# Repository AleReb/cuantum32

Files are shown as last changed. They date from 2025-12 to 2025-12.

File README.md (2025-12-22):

# Sistema de Análisis de Opiniones Distribuido I2C

## Changelog / Recent Updates (Quantum32 V3)
- **2025-12-22**:
  - **Fixed Blocking**: Master V3 now updates the OLED display continuously, even during high-speed Python batched sampling.
  - **Fixed Slave LED**: Slaves now explicitly use **Pin 7** for the status LED and give visual feedback on every I2C RX/TX event.
  - **Environment**: Fixed local Python environment initialization.

Sistema distribuido basado en Arduino que utiliza comunicación I2C para coordinar múltiples dispositivos esclavos que realizan análisis de opiniones (a favor/en contra/neutral). El maestro agrega los resultados y los muestra en una pantalla OLED con marcas de tiempo del RTC.

## 📋 Descripción

Este proyecto implementa una **simulación pedagógica de holografía (Toy Holography)** inspirada en el principio holográfico y la correspondencia AdS/CFT. Utiliza una arquitectura maestro-esclavo donde:

- **Maestro (Bulk)**: Representa el volumen ("bulk") del espacio-tiempo. Reconstruye información lógica a partir de las correlaciones de los esclavos, monitorea el ambiente y visualiza la "reconstrucción holográfica".
- **Esclavos (Boundary)**: Representan el borde ("boundary") del sistema. Generan observables locales con ruido y pérdida simulada que el maestro utiliza para inferir el estado del volumen.

El sistema ilustra cómo propiedades, corrección de errores y geometrías emergentes pueden surgir de interacciones distribuidas simples sobre un bus I2C.

## 🔧 Hardware Requerido

### Maestro (Master)
- 1x ESP32-S3 Super Mini (o compatible)
- 1x Pantalla OLED 1.3" (SH1106, dirección I2C 0x3C)
- 1x Módulo RTC DS3231 (dirección I2C 0x68)
- 1x Sensor BME280 (Temp/Hum/Pres, dirección I2C 0x76)
- 1x Módulo MicroSD (SPI: CS=7, MOSI=6, MISO=5, SCLK=4)
- 1x LED RGB (NeoPixel/WS2812B en pin 48)
- Resistencias pull-up 4.7kΩ (2x para SDA y SCL)

### Cada Esclavo (Slave)
- 1x Arduino (Uno, Nano, ESP32, etc.)
- Conexión al bus I2C compartido

### Adicional
- Cables jumper
- Fuente de alimentación adecuada (si se usan múltiples dispositivos)
- Protoboard o PCB para conexiones

### 2. Configurar el Maestro
1. Abrir `master.ino` en Arduino IDE
2. Revisar `config.h` para ajustar configuraciones si es necesario (pines, direcciones, habilitar/deshabilitar módulos)
3. Conectar el Arduino maestro
4. Seleccionar placa y puerto correcto
5. Cargar el código

### 3. Configurar los Esclavos
Para **cada esclavo**:
1. Abrir `slave.ino` en Arduino IDE
2. **IMPORTANTE**: Cambiar la dirección I2C única:
   ```cpp
   #define SLAVE_ADDRESS 0x10  // Cambiar a 0x11, 0x12, 0x13, etc.
   ```
3. Conectar el Arduino esclavo
4. Cargar el código
5. Repetir para cada esclavo adicional

### 4. Conexiones de Hardware
Ver [WIRING.md](WIRING.md) para diagramas detallados de conexión.

**Conexiones básicas I2C:**
- Conectar **SDA** de todos los dispositivos juntos
- Conectar **SCL** de todos los dispositivos juntos
- Conectar **GND** común
- Agregar resistencias pull-up de 4.7kΩ en SDA y SCL al voltaje de alimentación (3.3V o 5V según dispositivos)

## ⚙️ Configuración Avanzada

### Agregar Más Esclavos
1. Editar `config.h` en el maestro:
   ```cpp
   const uint8_t SLAVE_ADDRESSES[] = {
     SLAVE_ADDR_1,
     SLAVE_ADDR_2,
     SLAVE_ADDR_3,
     SLAVE_ADDR_4,
     0x14,  // Nuevo esclavo 5
     0x15   // Nuevo esclavo 6
   };
   ```
2. Programar nuevos esclavos con direcciones únicas
3. Conectar al bus I2C

### Habilitar/Deshabilitar Módulos
En `config.h` puedes activar o desactivar componentes:
```cpp
#define ENABLE_OLED       true   // Pantalla OLED
#define ENABLE_RTC        true   // Reloj RTC
#define ENABLE_SD_LOGGING true   // Registro en SD
#define ENABLE_BME280     true   // Sensor ambiental
#define ENABLE_RGB_LED    true   // LED de estado
```

### Ajustar Velocidad I2C
En `config.h`:
```cpp
#define I2C_CLOCK_SPEED 100000  // 100 kHz (estándar) o 400000 (rápido)
```

## 📊 Uso

### Monitor Serial
Abrir el monitor serial (115200 baud) para ver:
- Escaneo de dispositivos I2C al inicio
- Resultados agregados en tiempo real
- Confirmación de escritura en SD (`>> Data saved to SD`)
- Mensajes de error o advertencias

### Pantalla OLED (MasterV2)
La pantalla ahora visualiza la dinámica de la simulación en tiempo real:
- **Header**: `T:####` (Contador de Ticks de simulación).
- **Status Row**: Estado de cada esclavo (Cuadro lleno = OK, Vacío = Missing).
- **Bulk Reconstruction**: Barra de progreso que muestra qué porcentaje de la lógica del "bulk" ha sido recuperada exitosamente desde el borde.
  - El porcentaje se muestra centrado con contraste dinámico para evitar solapamiento.
- **Boundary Map (2x2)**: Visualización matricial del ruido en cada esclavo (cuadros más llenos = menos ruido/mejor señal).
- **History Graph**: Un gráfico histórico a la derecha que muestra la evolución de la `Reconstruction Ratio` en los últimos 40 ticks.
- **Footer**: Máscaras de bits (Boundary/Bulk) y datos ambientales.

### Registro en Tarjeta SD
El sistema registra en `datalog.csv`:
`timestamp, tick, active_slaves, boundary_mask, bulk_mask, recon_ratio, loss_sum, noise_avg, temp, hum`

### Disclaimer de "Veracidad Científica"
> [!IMPORTANT]
> **Nota sobre la precisión científica**:
> Este código es un **"modelo de juguete" (toy model)** con fines educativos y de prototipado.
> *   **No es** una simulación cuántica real (no hay entrelazamiento cuántico real ni hamiltonianos complejos).
> *   La "Reconstrucción del Bulk" usa una lógica de máscaras de bits simplificada para *ilustrar* conceptos de corrección de errores cuánticos, pero no implementa un código corrección de errores (QECC) riguroso como el código de HaPPY o Shor.
> *   Su objetivo es proveer una intuición física de cómo información local en el borde puede redundar en información robusta en el volumen, usando hardware clásico accesible.

## 🔍 Solución de Problemas

### No se detectan dispositivos I2C
- Verificar conexiones SDA/SCL
- Confirmar resistencias pull-up instaladas (4.7kΩ)
- Revisar alimentación de todos los dispositivos
- Usar sketch de escaneo I2C para detectar dispositivos

### OLED no muestra nada
- Verificar dirección I2C (0x3C o 0x3D)
- Confirmar librería correcta (SH1106 vs SSD1306)
- Revisar conexiones y alimentación

### Esclavos no responden
- Verificar direcciones únicas para cada esclavo
- Confirmar que los esclavos están alimentados
- Revisar que el código del esclavo se cargó correctamente
- Verificar timeout en `config.h` (aumentar si es necesario)

### Error en SD Card
- Verificar conexiones SPI (CS, MOSI, MISO, SCLK)
- Asegurar que la tarjeta está formateada en FAT32
- Revisar si el archivo `datalog.csv` está abierto en otro lugar

## 🛠️ Desarrollo Futuro

Posibles mejoras:
- [ ] Implementar checksums para validación de datos
- [ ] Agregar comandos de configuración desde el maestro
- [ ] Interfaz web para visualización remota
- [ ] Modo de bajo consumo para operación con batería
- [*] Implementar cuantum life! revisa la carpeta cuantum_life para ver el código del juego de la vida. 

## 👤 Autor

**Alejandro Rebolledo**  
Email: arebolledo@udd.cl  
Fecha: 2025-12-01  

**Atribución Original**
El código original fue creado por **Vicente Lorca** [@vlorcap](https://github.com/vlorcap) ; este proyecto es un derivado y el concepto inicial proviene de Vicente.

## 📄 Licencia

Este proyecto está licenciado bajo **Creative Commons Attribution-NonCommercial 4.0 International (CC BY-NC 4.0)**.

Ver el archivo [LICENSE](LICENSE) para más detalles.

### Descargo de Responsabilidad

Este código se proporciona "tal cual", sin garantías de ningún tipo, expresas o implícitas. El autor no se hace responsable de ningún daño o pérdida que pueda resultar del uso de este código. Úselo bajo su propio riesgo.

## 🤝 Contribuciones

Las contribuciones son bienvenidas. Por favor:
1. Fork el proyecto
2. Crea una rama para tu feature (`git checkout -b feature/AmazingFeature`)
3. Commit tus cambios (`git commit -m 'Add some AmazingFeature'`)
4. Push a la rama (`git push origin feature/AmazingFeature`)
5. Abre un Pull Request

## 📞 Soporte

Para preguntas o problemas, por favor abre un issue en el repositorio de GitHub.

---

**¡Gracias por usar este proyecto!** ⭐ Si te resulta útil, considera darle una estrella al repositorio.

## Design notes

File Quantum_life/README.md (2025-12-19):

# Cuantum Life: Holographic Edition (v1.2)

**Cuantum Life** is a specialized implementation of Conway's Game of Life for the **Cuantum32** hardware, merging "Fast Life" optimization with the "MasterV2" holographic architecture.

## The Concept

This project implements a **Holographic Universe** metaphor:

*   **The Bulk (OLED Screen)**: Represents the emergent spacetime where the "Life" simulation occurs.
*   **The Boundary (I2C Slaves)**: Represents the "holographic screen" or "event horizon" surrounding the universe.

In standard Game of Life, the universe is closed and often dies (heat death) or freezes (stable loops). In **Cuantum Life**, the universe is **open**. The I2C Slaves act as entropy sources, injecting fluctuations (random cells) into the Bulk:
1.  **Reactive**: If a slave detects high noise (from real-world sensors), it immediately injects life.
2.  **Spontaneous**: Even in silence, each slave acts as a quantum fluctuation source, injecting life automatically every 2-8 seconds.

See [game_of_life_concept.md](game_of_life_concept.md) for a full theoretical explanation.

## Controls

*   **Button A (GPIO 2)**: **Reset / Big Bang**. Restarts the unknown universe with a new random seed.
*   **Button B (GPIO 1)**: **Scale Toggle**. Switches between:
    *   *Scale 1*: 128x64 resolution (1 pixel per cell). High detail, slower.
    *   *Scale 2*: 64x32 resolution (2x2 pixels per cell). Chunky, retro, easier to see.

## Feedback Systems

### 1. Visual Feedback (OLED)
*   **Active Slaves**: Small circular indicators appear in the 4 corners of the screen if the corresponding Slave (0-3) is connected and active.
*   **Interaction Flash**: When a Slave injects "life" (entropy) into the system, its sector of the screen momentarily flashes inverted colors.

### 2. Status LED (NeoPixel)
The RGB LED acts as a "Universe Health Monitor", changing color based on **Population Density**:
*   **Blue/Cyan**: Low density (Sparse, expanding universe).
*   **Purple**: Medium density (Stable growth).
*   **Red**: High density (Crowded).
*   **White (Bright)**: Overpopulation or "Injection Flash" (Energy burst from boundary).

### 3. Serial Monitor (Debug)
Connect at **115200 baud** to see real-time statistics (1Hz):
*   `Gen`: Current generation number.
*   `Pop`: Total population count.
*   `Slaves`: Connectivity status and Noise levels for each node (e.g., `[0:OK N=0.45]`).

## Hardware Configuration (Cuantum32)

*   **Master**: ESP32
*   **Display**: SH1106 OLED (0x3C)
*   **Storage**: SD Card (HSPI: CS=7, MOSI=6, MISO=4, CLK=5)
*   **Feedback**: NeoPixel (Pin 48)
*   **I2C Slaves**: Addresses 0x10, 0x11, 0x12, 0x13.

## License

Creative Commons Attribution-NonCommercial 4.0 International (CC BY-NC 4.0).
**Author**: Alejandro Rebolledo (arebolledo@udd.cl)

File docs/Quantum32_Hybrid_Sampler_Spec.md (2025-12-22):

# Quantum32 Hybrid Sampler Spec
**Filename:** `docs/Quantum32_Hybrid_Sampler_Spec.md`  
**Project name:** **Quantum32 Hybrid Sampler (QHS)**  
**Status:** Implementable specification (Master/Slave **V3** derived from **V2**)  
**Primary goal:** Turn Quantum32 from a purely pedagogical “toy holography” demo into a **hardware-in-the-loop stochastic sampler** that a **PC/notebook** can use for **combinatorial optimization** (e.g., Max-Cut) and as a stepping stone toward **RBM negative-phase sampling**.

---

## 1. Scope and non-goals

### 1.1 In-scope
- Keep the existing **Master–Slave I2C** architecture.
- Use **V2 code style** (non-blocking, no fatal aborts) as the baseline.
- Implement **bidirectional** control:
  - **PC → Master → Slaves:** parameters and run control.
  - **Slaves → Master → PC:** **observables only** (no full state streaming for PoC).
- Provide a clean data contract so a **second AI** can work on the repo without guessing.

### 1.2 Explicit non-goals (for the PoC)
- No “all-training-on-ESP32”.
- No large state vectors over I2C.
- No guarantee of equilibrium or detailed-balance sampling.
- No claims of “quantum”; this is **stochastic classical sampling**.

---

## 2. Engineering constraints (must-haves)

These are repo-level rules for **all new code** (Master V3 and Slave V3):

1) **No `while(1){}`** to indicate fatal errors.  
2) **No `return;` inside `setup()`** to abort boot.  
3) Always continue initialization; use:
   - **global boolean flags** per subsystem  
   - **Serial diagnostics** in `loop()`  
   - periodic **retry** using `millis()` scheduling  
4) No heavy work inside I2C callbacks (`onReceive`, `onRequest`).

---

## 3. Repository baseline

### 3.1 Relevant folders (current repo)
- `masterV2/masterV2.ino` — non-blocking master baseline
- `cuantumsV2/cuantumsV2.ino` — non-blocking slave baseline
- `master/config.h` — useful pin definitions and feature flags (even if V2 currently uses defaults)
- `docs/` — conceptual and visualization documents
- `WIRING.md` — wiring notes

### 3.2 Current V2 data protocol (as implemented)
**Slave receives (from Master)**
- Tick command:  
  `T,<tick>,<mode>,<noise>\n`  
  Parsed in slave V2 via `parseTickCommand(...)`.

**Slave responds (to Master on I2C request)**
- Observable response:  
  `O,<tick>,<bmask>,<loss>,<noise>,<seed>\n`

**Master parses (from Slave)**
- `sscanf(buf, "%c,%lu,%u,%u,%f,%lu", &prefix, &tick, &bmask, &loss, &noise, &seed)`

This spec keeps those **as the compatible baseline**.

---

## 4. Target architecture (Hybrid Sampler)

### 4.1 Roles
**Hardware**
- Runs **p-bit-like dynamics** on each slave.
- Emits **observables** (compact summaries) that represent sampled configurations.
- Applies parameters from PC (via Master).

**PC/Notebook**
- Defines an objective (e.g., Max-Cut on a graph).
- Requests batches, evaluates scores, and updates parameters (annealing schedule or learned control).
- Logs and plots metrics (mixing/diversity) to validate PoC.

### 4.2 Minimal hybrid loop
1) PC connects to Master over USB Serial.
2) PC sets parameters (T, bias, coupling, mode).
3) Master pushes params to all slaves over I2C.
4) PC requests a batch of **K** samples; Master orchestrates ticks and collects observables.
5) PC computes:
   - Max-Cut score (or other objective)
   - diversity and autocorrelation metrics
6) PC updates parameters and repeats.

---

## 5. Data model: Observables

### 5.1 Per-slave observable record
A single record corresponds to “what one slave produced for a given tick”.

| Field | Type | Meaning | Notes |
|---|---:|---|---|
| `tick` | uint32 | global tick id | set by Master |
| `slave_id` | uint8 | index of slave in Master list | added by Master when streaming to PC |
| `bmask` | uint16 | compact boundary configuration | treated as “observable microstate” |
| `loss` | uint16 | proxy loss / mismatch counter | pedagogy or objective proxy |
| `noise` | float (2–3 dp) | effective temperature | should match parameter T |
| `seed` | uint32 | PRNG state / nonce | helps debug non-determinism |

**Why `bmask` counts as “observable”:** it is not the full internal state; it is a compact, lossy view that is enough for PoC optimization and sampler validation.

### 5.2 Batch stream format to PC
To keep parsing robust, Master MUST prefix machine-readable lines with `@` (control) and use `O,` lines strictly for data.

Example:
```
@BATCH RUN=12 T=0.20 B=10 Kp=40 M=1 K=100 STRIDE=1 BURN=20
O,1234,0,9,2,0.20,30123456
O,1234,1,3,0,0.20,99123001
...
@DONE RUN=12 LASTTICK=1333
```

---

## 6. Parameter model (PC → hardware)

### 6.1 Parameters to control (PoC)
| Name | Symbol | Type | Range | Meaning |
|---|---|---|---|---|
| Noise / Temperature | `T` | float | 0.00–1.00 | flip intensity / randomness |
| Bias | `B` | int8 | -127..127 | pushes configurations toward 0/1 patterns |
| Coupling | `Kp` | uint8 | 0..255 | introduces correlation / smoothness |
| Mode | `M` | uint8 | 0..255 | selects dynamics variant |

**Notes**
- V2 already supports `T` and `M` (via the tick command).
- V3 introduces `B` and `Kp` and moves parameters into a dedicated command (recommended).

### 6.2 Annealing schedules (PC side)
Two supported patterns:
1) **Manual schedule:** PC sweeps T from high → low.
2) **Adaptive schedule:** PC updates T/B/Kp based on score improvements.

---

## 7. Communication protocols

### 7.1 I2C: Master ↔ Slaves
**Constraints**
- Typical I2C read buffer is small; V2 uses **≤32 bytes** reads.
- Keep message lengths under 32 bytes for PoC. Avoid chunking in V3 unless needed.

#### 7.1.1 V3 I2C commands
To keep compatibility, do not break V2; add one new command type.

1) **SET_PARAMS** (new in V3)  
   `P,<T>,<B>,<Kp>,<M>\n`  
   - Sent infrequently (only when parameters change).
   - Slaves store parameters; do not compute heavy updates inside callback.

2) **TICK** (existing V2)  
   Keep V2 tick for synchronization:
   - Option A (compatible): `T,<tick>,<M>,<T>\n`
   - Option B (cleaner): `T,<tick>\n` and rely on last `P` for params.

**Recommendation:** Use **Option B** in V3 (short, robust) once `P` exists; keep Option A as fallback during migration.

#### 7.1.2 Slave response (unchanged)
`O,<tick>,<bmask>,<loss>,<noise>,<seed>\n`

### 7.2 Serial: PC ↔ Master
**Transport:** USB Serial @ 115200 (default)

#### 7.2.1 PC → Master commands
- `@HELLO`
- `@SET T=0.20 B=10 Kp=40 M=1`
- `@GET K=200 STRIDE=1 BURN=20`
- `@STOP`

#### 7.2.2 Master → PC responses
- `@HELLO OK FW=MasterV3 SLAVES=4`
- `@ACK ...` / `@ERR ...`
- `@STATUS ...` (periodic health)
- `@BATCH ...`, data lines `O,...`, `@DONE ...`

---

## 8. Non-blocking state machines

### 8.1 Master V3 state machine
- `BOOT`
- `INIT` (set flags; never abort)
- `IDLE` (wait for PC commands)
- `APPLY_PARAMS` (push `P` to all slaves with retry counters)
- `SAMPLING`
  - schedule ticks
  - request slave responses
  - stream `O,...` lines to PC
- `DEGRADED` (optional) if I2C is down; still respond to PC with errors and status

**Non-blocking rule:** each `loop()` iteration must do a small bounded amount of work (e.g., poll one slave per loop).

### 8.2 Slave V3 state machine
- `BOOT`
- `READY`
- `RX_PENDING` (flag set by `onReceive`)
- `DYNAMICS_STEP` (time-sliced updates)
- `BUILD_TX` (prepare `O,...` response in a buffer)
- `REQUEST` (I2C request event reads the prepared buffer only)

---

## 9. Failure policy and observability

### 9.1 Master global flags (minimum)
- `bool i2cOK`
- `bool pcLinkOK` (recent Serial command seen)
- `bool slaveOK[NUM_SLAVES]` (timeout-based, e.g., lastRxMs)
- optional peripheral flags if enabled later: `sdOK`, `oledOK`, `rtcOK`, `bmeOK`, `rgbOK`

### 9.2 Retry policy
- I2C init retry every 2–5 s if bus failed.
- Per-slave command retry counters for `P` and `T` (do not stall the whole system if one slave fails).
- If a slave is missing, keep sampling with remaining slaves.

### 9.3 Logging
- Serial logs for humans:
  - `[INIT] ...`, `[I2C] ...`, `[WARN] ...`
- Serial stream for PC:
  - `@...` control + `O,...` data

SD logging is optional for PoC; if enabled, log **batches** rather than every tick to reduce overhead.

---

## 10. PoC acceptance criteria

The PoC is “approved” if the following can be shown with plots/logs:

### 10.1 Operational robustness
- Runs for **≥30 minutes** without lockups, while:
  - one slave is unplugged/replugged, and/or
  - PC disconnects/reconnects Serial.

### 10.2 Sampler behavior vs temperature
For at least 3 T values (e.g., 0.05, 0.20, 0.50), using K≥200 samples per condition:
- **Diversity increases with T**
  - `unique(bmask)/K` increases as T increases
- **Autocorrelation decreases with T**
  - correlation time (lag where autocorr < 0.2) decreases as T increases

### 10.3 Optimization utility (Max-Cut demo)
Using a small fixed graph (ring or random sparse graph):
- Best Max-Cut score found at low T is **≥** best score at high T baseline.
- A basic annealing schedule T high → low improves best score over fixed T.

---

## 11. Implementation plan (recommended PR sequence)

### PR-1: Serial protocol on Master (no sampling changes)
- Add `@HELLO`, `@SET`, `@GET`, `@STOP`
- Add `@STATUS` periodic line
- Keep V2 I2C tick/response unchanged

### PR-2: Add `P` command (SET_PARAMS) end-to-end
- Master: send `P,<T>,<B>,<Kp>,<M>`
- Slave: parse `P` in loop (non-blocking)
- Keep `T` as synchronization tick only

### PR-3: Sampling driver + batching
- Master: orchestrate burn-in, stride, K batch size
- Stream `@BATCH`, `O,...`, `@DONE`

### PR-4: PC reference client + metrics
- Python:
  - connect, set params, request batches
  - compute diversity + autocorrelation
  - compute Max-Cut objective from bmask mapping
  - export CSV

### PR-5: Documentation + reproducible demo
- Update `docs/` with:
  - wiring assumptions
  - run commands
  - expected output examples
  - plots for PoC criteria

---

## 12. Files to add to the repository

Recommended additions (keep current folders intact):
- `docs/Quantum32_Hybrid_Sampler_Spec.md` (this file)
- `masterV3/` (new)  
  - `masterV3.ino`
- `cuantumsV3/` (new)  
  - `cuantumsV3.ino`
- `pc/` (new)
  - `pc_client_maxcut.py`
  - `metrics.py`
  - `sweep_params.py` (optional)

---

## 13. Reference: mapping bmask to optimization variables

For PoC Max-Cut, treat bits of each slave’s `bmask` as binary variables.

Example:
- `NUM_SLAVES = 4`
- use lower 4 bits of each `bmask` → total **16** variables
- concatenate as: `x = [b0..b3 from slave0, b0..b3 from slave1, ...]`

Max-Cut score:
- For each edge (i, j) with weight w:
  - add w if `x[i] != x[j]`

This is intentionally simple and makes the system immediately useful for “annealing-as-a-service”.

---

## 14. Notes for future extension (RBM / negative phase)

Once the PoC is stable:
- interpret the hardware sampler as a **negative-phase sampler**
- PC computes gradient updates for an RBM using:
  - positive phase from data
  - negative phase from hardware samples (bmask-derived variables)
- Start with tiny RBM (e.g., 8 visible + 8 hidden) and map couplings into local rules gradually.

No RBM claims are part of the PoC; this is a roadmap.

---

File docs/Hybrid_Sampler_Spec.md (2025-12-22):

# Hybrid Sampler Spec (Quantum32)

**Repository:** Quantum32 (ESP32-S3 master + multiple I2C slaves)  
**Goal:** Extend the existing I2C master/slave architecture to support a *hybrid training loop* where:
- **Hardware (ESP32 + I2C slaves)** acts as a **non-deterministic sampler** (state generator).
- **PC/Notebook** performs **parameter updates / gradient computation** and requests new samples from hardware.

This document is designed to be explicit enough for another AI (or developer) to implement work in this repo without needing extra context.

---

## 1. Current repository layout (as shipped in the ZIP)

Root (high-level):
- `master/`  
  - `master.ino` (I2C Master v1: aggregates slave results)  
  - `config.h` (feature flags, addresses, pins)
- `masterV2/`  
  - `masterV2.ino` (Master v2 variant)
- `cuantums/`  
  - `cuantums.ino` (Slave v1: returns opinion counts)
- `cuantumsV2/`  
  - `cuantumsV2.ino` (Slave v2: “Non-Blocking” boundary node)
- `docs/`  
  - `quantum_spacetime_sim.md` (conceptual simulation doc)  
  - `visualization_guide.md` (visual interpretation guide)  
  - PDFs (background material)
- `WIRING.md`, `I2C_FIXES.md`, `OLED_MIGRATION.md`, `RGB_LED_GUIDE.md`, `concept.md`, `README.md`
- CAD + Eagle files: `modelo_3d_cuantum32/`, `Cuantum32/`, etc.

**Important:** The existing system already implements:
- Master polling slaves via I2C
- Slaves responding with a compact payload (v1 uses a CSV-like string)
- Optional peripherals controlled by flags (OLED, RTC, SD, BME280, RGB LED)

This spec **extends**; it does not rewrite the architecture.

---

## 2. Terminology

- **Master:** ESP32-S3 device coordinating the network; connected to PC via USB Serial.
- **Slave / Boundary Node:** I2C node returning a payload on request.
- **Sample:** A discrete system state returned to the PC, suitable for “negative phase” sampling (or at minimum, a structured observable derived from that state).
- **Parameters:** Control variables sent from PC → Master → Slaves (e.g., temperature/noise, bias, coupling scalar, or other model parameters).
- **PoC:** Proof-of-concept milestone, minimal but defendable.

---

## 3. Non-negotiable engineering constraints (repo style)

These constraints must be preserved across all new code:

1) **No `while(1){}` infinite blocks** for “fatal error” handling.  
2) **No `return;` from `setup()`** to abort initialization.  
3) Always continue with remaining initializations, using:
- **global boolean flags** for each subsystem  
- **Serial diagnostic messages** in `loop()`  
- optional **retries** (non-blocking; time-based backoff)

This applies to **Master and Slaves**.

---

## 4. What must be defined before writing code

### 4.1. Select baseline firmware versions
Decide which files are the active baseline:
- Master: `master/master.ino` + `master/config.h` **or** `masterV2/masterV2.ino`
- Slave: `cuantumsV2/cuantumsV2.ino` (preferred due to “non-blocking” approach) or `cuantums/cuantums.ino`

**Default recommendation for PoC:** Master v1 + Slave v2 (least disruption; preserves config flags).

### 4.2. Define “sample” for PoC (minimal viable)
Choose one of these formats:

**Option A — Observables only (fastest):**
- Keep current (favor/contra/neutral) and add at least 1–2 extra observables (e.g., local “energy” proxy, magnetization-like scalar).
- Pros: minimal refactor.
- Cons: not a full state sampler.

**Option B — Full discrete state (recommended):**
- Each slave returns a bitset/spin vector chunk (e.g., 8–32 bits).
- Master concatenates into N-bit state and forwards to PC.
- Pros: true sampler; enables mixing/diversity metrics properly.
- Cons: requires defining a compact binary payload.

**PoC target:** Option B with N = 32 or 64 bits.

### 4.3. Define parameter set (PC → hardware)
Minimal parameter set (PoC):
- `T` (temperature/noise strength) : uint8 or fixed-point
- `B` (global bias) : int8
- `K` (global coupling scalar) : uint8 or fixed-point

Optional later:
- per-node bias vector
- per-edge coupling list or sparse adjacency

### 4.4. Define update cadence
- `burn_in_steps` (discarded steps after parameter change)
- `stride` (steps between returned samples)
- `K_samples` (batch size returned per request)

---

## 5. System overview (hybrid loop)

### 5.1. Responsibilities

**Hardware (Master + Slaves)**
- Maintain discrete system dynamics.
- Accept parameters and apply them.
- Generate samples (states/observables) upon request.
- Provide status/health information.

**PC/Notebook**
- Request samples, collect batches.
- Compute metrics:
  - autocorrelation / correlation time (mixing)
  - diversity (unique states, Hamming distance)
  - entropy proxy
- Optionally compute parameter updates (training loop).

### 5.2. High-level sequence

1) PC connects via Serial to Master.
2) PC sends `SET_PARAMS`.
3) Master distributes params to all Slaves via I2C.
4) PC sends `REQUEST_SAMPLES(K)`.
5) Master triggers sampling and returns K samples (or aggregated batch).
6) PC computes metrics and decides next params; loop repeats.

---

## 6. Communication specifications

### 6.1. PC ↔ Master transport
- Transport: USB Serial (115200 default)
- Protocol: framed messages (recommended), not raw CSV logs.

**Must define:**
- framing (start byte/marker, length, type, payload, checksum)
- timeouts and retries
- version field for forward compatibility

### 6.2. Master ↔ Slave transport
- Transport: I2C
- Current master code requests up to 32 bytes (`Wire.requestFrom(address, 32)` in v1), so design payloads accordingly.
- If payload > 32 bytes, define chunking (page index + total pages).

**Payload type must be explicit:**
- `SAMPLE_STATE` (binary bitset recommended)
- `STATUS` (health + counters)
- `ACK` for parameter updates (optional but recommended)

---

## 7. Message formats (normative)

### 7.1. PC ↔ Master (Serial)

Define message types (minimum set):
- `HELLO` (PC → Master): request protocol/version/status
- `STATUS` (Master → PC): flags + counts
- `SET_PARAMS` (PC → Master): {T, B, K, burn_in, stride}
- `GET_SAMPLES` (PC → Master): {K_samples}
- `SAMPLES` (Master → PC): batch payload

**Batch payload requirements:**
- include `run_id` / `seq`
- include `timestamp_ms` (from millis) for ordering
- include `params_hash` so PC can confirm which params produced the batch

### 7.2. Master ↔ Slave (I2C)

Define I2C commands (1-byte opcodes):
- `0x01 SET_PARAMS`
- `0x02 GET_SAMPLE`
- `0x03 GET_STATUS`

Define payload layout for `SET_PARAMS` (fixed-size):
- Byte0: opcode
- Byte1: T
- Byte2: B (two’s complement)
- Byte3: K
- Byte4–5: burn_in_steps (uint16)
- Byte6–7: stride (uint16)

Define payload layout for `GET_SAMPLE` response (example for 32-bit state):
- Byte0: sample_id (uint8 rolling)
- Byte1–4: state_bits (uint32, little-endian)
- Byte5: observables (optional flags)
- Byte6: checksum (optional)
- Remaining bytes unused/reserved

If N > 32, use chunking:
- Byte0: sample_id
- Byte1: chunk_index
- Byte2: chunk_count
- Byte3–(3+chunk_len-1): chunk_bits
- Last byte: checksum (optional)

---

## 8. State machines (implementation guidance)

### 8.1. Master state machine
- `BOOT`
- `INIT_PERIPHERALS` (sets flags; never aborts)
- `IDLE`
- `APPLY_PARAMS` (distribute to slaves; track per-slave success)
- `SAMPLING` (collect K samples; store in buffer; non-blocking loop)
- `STREAM_TO_PC` (serialize and send batch; non-blocking)

### 8.2. Slave state machine
- `BOOT`
- `READY`
- `RUN_DYNAMICS` (continuous background updates, time-sliced)
- `ON_SET_PARAMS` (apply; reset burn-in counters)
- `ON_GET_SAMPLE` (return latest sampled state or generate on-demand)

**Key requirement:** sampling must not block I2C callbacks for long time.  
Use cached/latest state or minimal work during request callback.

---

## 9. Reliability & observability

### 9.1. Global flags (mandatory)
Master must track:
- `i2c_ok`
- `serial_ok` (link active / last command time)
- `sd_ok`
- `oled_ok`
- `rtc_ok`
- `bme_ok`
- `rgb_ok`
- `slave_ok[i]` (per slave)

Slaves must track:
- `i2c_ok`
- `params_ok`
- `dynamics_ok`
- counters: `set_params_count`, `sample_count`, `i2c_errors`

### 9.2. Retry policy
- No blocking loops.
- Use `millis()` scheduling with backoff:
  - e.g., retry I2C init every 2–5 seconds if failed
  - retry SD init periodically if missing card

### 9.3. Logging policy
- Master logs to Serial periodically:
  - flags summary
  - per-slave last seen
  - sample throughput
- Optional SD logging:
  - `run_id, seq, params, sample_count, error_counts`

---

## 10. Validation metrics (PC-side) to accept PoC

Minimum metrics to compute from returned states:

1) **Diversity**
- unique states ratio
- mean Hamming distance between consecutive samples

2) **Mixing**
- autocorrelation vs lag for a few bits
- estimate correlation time (lag where autocorr < threshold)

3) **Stability**
- distribution of basic observables (e.g., magnetization proxy) stable under same params
- predictable change when T changes

**PoC acceptance criteria (pragmatic):**
- With fixed params, sampler produces > X unique states in K samples
- Autocorrelation decays (not flat at 1)
- Increasing T increases diversity/entropy proxy

---

## 11. Implementation milestones (recommended PR sequence)

**PR-1: Protocol skeleton**
- Add Serial framing + command parser on Master
- Implement `HELLO/STATUS` end-to-end
- No sampling changes yet

**PR-2: Param distribution**
- Implement `SET_PARAMS` PC→Master, Master→Slaves
- Add per-slave ACK/status

**PR-3: Sample payload**
- Implement `GET_SAMPLE` I2C opcode + binary response
- Master concatenates into N-bit state and sends `SAMPLES`

**PR-4: PC reference client**
- Python scripts:
  - connect, set params, request batch
  - compute metrics and export plots

**PR-5: Documentation + demo**
- Update `docs/` with diagrams, run instructions, expected outputs

---

## 12. Files to add (proposed)

Inside repo:
- `docs/Hybrid_Sampler_Spec.md` (this file)
- `pc/` (or `tools/pc/`) for Python client:
  - `client.py`
  - `metrics.py`
  - `plot.py`
- Optional: `protocol/` with a single source of truth:
  - `protocol.md` (opcode tables, frame format)
  - `protocol.h` (shared constants for firmware)

---

## 13. Run instructions (baseline)

1) Flash Master firmware (baseline + protocol skeleton).
2) Flash N slave nodes (unique I2C addresses).
3) Verify on Serial:
- peripherals flags
- slave discovery / polling
4) Run PC client:
- `HELLO`
- `SET_PARAMS`
- `GET_SAMPLES`
5) Confirm metrics output.

---

## 14. Notes for contributors (and other AIs)

- Do not change existing peripheral wiring assumptions unless also updating `WIRING.md`.
- Keep payload sizes compatible with I2C constraints; prefer binary over CSV for sampling.
- Avoid heavy computation in I2C callbacks.
- All new features must degrade gracefully when a module is missing.
- Keep “educational visualization” features (OLED/RGB) optional and independent of sampling path.

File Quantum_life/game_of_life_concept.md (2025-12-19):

# Cuantum Life: Una Interpretación Holográfica del Juego de la Vida

## 1. Introducción: ¿Qué es el Juego de la Vida?

El **Juego de la Vida** (Game of Life) no es un juego tradicional con ganadores o perdedores, sino un **autómata celular** diseñado por el matemático británico **John Horton Conway** en 1970.

Se desarrolla en una cuadrícula infinita (o finita, en nuestro caso) de células que pueden estar en dos estados: **viva** o **muerta**. El "juego" evoluciona por turnos (generaciones) siguiendo reglas matemáticas muy simples que, sorprendentemente, generan comportamientos complejos, caóticos y a veces similares a la vida biológica.

### Las 3 Reglas de Conway:
1.  **Supervivencia**: Una célula viva con 2 o 3 vecinas vivas, sigue viva.
2.  **Muerte**:
    *   Por **Soledad**: Si tiene menos de 2 vecinas (se aísla).
    *   Por **Sobrepoblación**: Si tiene más de 3 vecinas (se asfixia).
3.  **Nacimiento**: Una célula muerta con exactamente 3 vecinas vivas, "nace" (revive).

A partir de estas reglas emergen patrones estables ("bloques"), osciladores ("parpadeadores") y naves espaciales ("gliders") que se desplazan por el tablero.

---

## 2. El Concepto Cuantum

Este proyecto reinterpreta este clásico bajo el marco conceptual de la **Holografía** y la **Termodinámica Cuántica** (simulada), utilizando la arquitectura de hardware **Cuantum32**.

En lugar de ser un autómata celular cerrado y aislado, nuestro "Universo" (la matriz de LEDs OLED) es un sistema abierto que recibe influencia constante de su "Borde" (los Esclavos I2C).

## 3. Analogía Físico-Teórica

| Componente | Rol en Game of Life | Interpretación Holográfica |
| :--- | :--- | :--- |
| **Matriz OLED (Bulk)** | El tablero de juego (128x64 o 64x32) | **El Espacio-Tiempo Emergente**: Donde ocurre la física visible, la materia y la interacción. Es una proyección. |
| **Esclavos I2C (Borde)** | Sensores / Generadores de Ruido | **La Frontera (Boundary CFT)**: Donde reside la información "real". Las fluctuaciones en el borde excitan el bulk. |
| **Evolución (Reglas)** | Nacimiento/Muerte de células | **Leyes Físicas Locales**: La dinámica interna del universo. |
| **Seed / Ruido (I2C)** | Inyección de células aleatorias | **Entalpía / Fluctuaciones Cuánticas**: Energía que entra desde el borde, impidiendo la muerte térmica del universo. |

## 4. Dinámica del Sistema

### 4.1 El Problema del Universo Cerrado
En una implementación clásica del Juego de la Vida, el sistema es cerrado. Eventualmente, tiende a:
1.  **Estabilidad Estática**: Bloques, beehives (Muerte térmica).
2.  **Ciclos Periódicos**: Blinkers, toads (Cristales de tiempo).
3.  **Vacío**: Extinción total.

### 4.2 La Solución Cuantum: Universo Abierto
En **Cuantum Life**, el universo nunca se cierra completamente. Los esclavos actúan como "fuentes de vida" (o perturbación) ubicadas en el horizonte de sucesos (el borde físico o lógico del sistema).

- **Interacción**: Cuando un esclavo reporta actividad (o un nivel alto de "Ruido/Entropía"), inyecta células vivas en su cuadrante correspondiente del Bulk.
- **Corrección de Errores**: Si el Bulk entra en un estado de bucle infinito (detectado por el algoritmo de Hash), el sistema puede consultar al Borde para solicitar una "Semilla de Reinicio" (una nueva configuración inicial basada en la entropía del borde), en lugar de usar un simple `random()`.

## 5. Implementación en Hardware

- **El Maestro (ESP32)**: Sostiene la realidad del Bulk. Ejecuta las reglas de Conway a alta velocidad.
- **Los Esclavos**: Son observadores y perturbadores.
    - *Si un esclavo está ausente*: Esa región del borde es "fría" (vacío).
    - *Si un esclavo está presente*: Esa región irradia partículas (gliders o ruido) hacia el centro.

Esta arquitectura convierte al *Juego de la Vida* en una visualización de la salud y estado de la red de sensores. Un sistema con muchos esclavos activos será un universo caótico y lleno de vida. Un sistema desconectado será un universo estático y moribundo.

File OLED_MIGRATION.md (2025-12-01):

# Cambio de Librería OLED: Adafruit → U8g2

## ✅ Cambios Completados

Se migró exitosamente la librería de control de la pantalla OLED de **Adafruit_GFX/SH1106** a **U8g2** por olikraus.

## 📝 Archivos Modificados

### 1. [config.h](file:///c:/Users/Ale/Dropbox/clases_universidad/cuantum32/config.h)
**Cambios**:
- Eliminadas definiciones de `OLED_WIDTH`, `OLED_HEIGHT`, `OLED_RESET`
- Reemplazados defines `USE_SH1106` / `USE_SSD1306` por `USE_SH1106_128X64` / `USE_SSD1306_128X64`
- Actualizada documentación para reflejar constructores U8g2

### 2. [master.ino](file:///c:/Users/Ale/Dropbox/clases_universidad/cuantum32/master.ino)
**Cambios**:
- **Includes**: Reemplazado `Adafruit_GFX.h` y `Adafruit_SH1106.h` por `U8g2lib.h`
- **Constructor**: Cambiado de `Adafruit_SH1106 display(OLED_RESET)` a `U8G2_SH1106_128X64_NONAME_F_HW_I2C display(U8G2_R0, U8X8_PIN_NONE)`
- **Inicialización**: Simplificado de `display.begin(OLED_ADDRESS)` a `display.begin()`
- **API de dibujo**: Migrado completamente a U8g2:
  - `clearDisplay()` → `clearBuffer()`
  - `display()` → `sendBuffer()`
  - `setTextSize()`, `setTextColor()`, `setCursor()`, `print()` → `setFont()`, `drawStr()`, `sprintf()`
  - `drawLine()` → `drawLine()` (mismo nombre, diferente sintaxis)

### 3. [README.md](file:///c:/Users/Ale/Dropbox/clases_universidad/cuantum32/README.md)
**Cambios**:
- Actualizada sección de librerías requeridas
- Cambiadas instrucciones de instalación para U8g2
- Removidas referencias a Adafruit_GFX y Adafruit_SH1106

## 🔄 Comparación de APIs

| Función | Adafruit | U8g2 |
|---|---|---|
| Inicializar | `display.begin(address)` | `display.begin()` |
| Limpiar buffer | `display.clearDisplay()` | `display.clearBuffer()` |
| Enviar a pantalla | `display.display()` | `display.sendBuffer()` |
| Configurar fuente | `display.setTextSize(1)` | `display.setFont(u8g2_font_6x10_tr)` |
| Dibujar texto | `display.print("texto")` | `display.drawStr(x, y, "texto")` |
| Línea horizontal | `display.drawLine(x1,y1,x2,y2,color)` | `display.drawLine(x1,y1,x2,y2)` |

## ✨ Ventajas de U8g2

1. **Mejor rendimiento**: Más rápido y eficiente en memoria
2. **Soporte nativo SH1106**: Mejor compatibilidad con pantallas de 1.3"
3. **Más fuentes**: Gran variedad de fuentes integradas
4. **API más limpia**: Funciones más directas y predecibles
5. **Amplio soporte**: Compatible con múltiples controladores OLED

## 📦 Librería Requerida

**Nombre**: U8g2  
**Autor**: olikraus  
**Instalación**: Arduino IDE → Library Manager → Buscar "U8g2"

## 🎨 Fuentes Utilizadas

- `u8g2_font_ncenB08_tr` - Título (negrita, 8pt)
- `u8g2_font_6x10_tr` - Texto normal (6x10 pixels)

## 🔧 Configuración Actual

```cpp
// En config.h
#define USE_SH1106_128X64  // Para OLED 1.3" SH1106

// Constructor en master.ino
U8G2_SH1106_128X64_NONAME_F_HW_I2C display(U8G2_R0, U8X8_PIN_NONE);
```

## ✅ Verificación

- ✅ Código compila sin errores
- ✅ API U8g2 implementada correctamente
- ✅ Documentación actualizada
- ✅ Configuración centralizada en config.h
- ✅ Soporte para SH1106 y SSD1306

---

**Migración completada exitosamente** 🎉

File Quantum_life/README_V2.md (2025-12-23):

# Quantum Life V2.1 — Holographic Sampler Integration

Este es el firmware avanzado (**V2.1**) para el Master del Juego de la Vida, diseñado para integrarse con los esclavos **quantumV3**.

## 🚀 Novedades de la V2.1

### 1. Resolución 1:1 (Alta Densidad)
Se ha habilitado la resolución completa de **128x64** píxeles (1 píxel por célula). Esto permite observar patrones mucho más complejos y detallados en la pantalla OLED.

### 2. Smart Loop Break (Detección de Bucles)
El sistema ahora detecta automáticamente si el juego se queda "congelado" o entra en un ciclo infinito mediante un buffer de hashes 32-bit (FNV-1a).
- **Alerta**: Si se detecta un bucle, aparece un mensaje en pantalla y el NeoPixel parpadea en **ROJO** durante 10 segundos.
- **Salida Holográfica**: Si hay esclavos conectados, su entropía se usa para "romper" el bucle inyectando patrones. Si no hay esclavos, el sistema entra en un "Estado Cuántico Puro" (congelado) hasta que el usuario reinicie.

### 3. Gravedad Holográfica
Se ha implementado una fuerza de atracción virtual. Los cuadrantes donde hay esclavos activos generan una "gravedad" que sesga las reglas del juego, facilitando que las células vivas se agrupen cerca del hardware conectado.

### 4. Optimización Bit-Parallel (High FPS)
Se ha implementado un motor de cálculo paralelo (Bit-Parallel GoL) que permite procesar columnas completas de 64 bits de forma simultánea. Esto garantiza una ejecución fluida incluso en la resolución completa de 128x64.

### 6. Entropía Ambiental (BME280)
El sistema ahora vincula la inyección de vida al clima local:
- **Temperatura Base**: 10% de inyección a 21°C.
- **Escalado**: Sube o baja ±0.5% por cada grado de diferencia.
- **Suelo de Seguridad**: Si hay esclavos, la inyección nunca baja del **1%**. Si no hay, queda en **0%**.
- **Throttling**: Se mantiene la pausa si la población supera el 20%.

### 7. Robustez I2C (Hot-swap v4 - Hybrid Engine)
Se han adoptado técnicas del motor industrial "Hybrid Sampler" para garantizar estabilidad total:
- **Parser Dual**: El sistema ahora reconoce tanto el protocolo **Largo** como el **Compacto**, siendo más resistente a datos ruidosos.
- **Polling Escalonado (Breather delay)**: Se ha añadido un retardo de **4ms** entre las peticiones a cada esclavo. Esto permite que la capacitancia del bus se estabilice tras el ruido de inserción.
- **Timeouts de 200ms**: Tiempo extendido para permitir que esclavos con mucha carga de trabajo respondan sin bloquear al Master.
- **Ping de Pre-vuelo**: Validación de presencia antes de solicitar datos para evitar cuelgues de hardware.

## 🛠️ Guía de Uso

1. **Botón A**: 
   - **Click Corto**: Reiniciar juego (o despertar de estado congelado).
   - **Mantener (>2s)**: Guardar **SVG** en la tarjeta SD.
2. **Botón B**: Alternar Resolución (128x64 <-> 64x32).
3. **Monitor OLED**: 
   - Verás `GEN` (Generación), `POP` (Población), `T` (Ruido) y `Kp` (Acoplamiento).
   - Indicador visual del escudo cuando está activo.

---
> [!NOTE]
> El sistema requiere al menos un esclavo quantumV3 para procesar la salida de bucles complejos de forma automática. De lo contrario, el juego se detendrá al detectar un estado estático para evitar desperdicio de ciclos.

## Descargo de Responsabilidad
Este software se ofrece 'tal cual', sin garantías de ningún tipo. El usuario lo utiliza bajo su propio riesgo.

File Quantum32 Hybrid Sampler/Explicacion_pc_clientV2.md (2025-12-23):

# Explicación del Cliente Quantum32 Max-Cut V2 (Dashboard Nativo)

El `pc_client_maxcutV2.py` es una aplicación de escritorio diseñada para controlar y visualizar el **Quantum32 Hybrid Sampler** en tiempo real. Utiliza la librería **Dear PyGui** para ofrecer una interfaz fluida con renderizado por GPU.

## 🏗️ Arquitectura del Sistema

El cliente funciona como el "Cerebro" que coordina al Master (ESP32) y procesa los datos de los Slaves.

```mermaid
graph TD
    subgraph PC (Python Client V2)
        GUI[Interface Dear PyGui]
        ANN[Lógica de Annealing]
        DRAW[Drawing API - Gráfico Circular]
    end

    subgraph Hardware
        M[Master ESP32]
        S1[Slave 1]
        S2[Slave 2]
        Sn[Slave n...]
    end

    GUI <-->|Serial CMDs| M
    M <-->|I2C| S1 & S2 & Sn
    ANN -->|Dynamic Noise| GUI
    GUI --> DRAW
```

## 🚀 Características Principales

### 1. Dashboard en Tiempo Real
- **Evolución del Score**: Gráfico lineal que muestra cómo el sistema encuentra mejores soluciones con el tiempo.
- **Distribución de Scores**: Histograma que ayuda a entender la calidad de las muestras.
- **Métricas**: Score actual, mejor score histórico, eficiencia y contador de muestras.

### 2. Gráfico de Partición Circular
Visualiza el problema de **Max-Cut** directamente:
- **Nodos**: Representan los bits del sistema (16 bits en anillo).
- **Colores**: Cambian dinámicamente. El rojo y el verde indican los dos grupos ("partitions") del corte.
- **Aristas (Edges)**: Se iluminan cuando la conexión entre dos nodos contribuye al puntaje del corte.

### 3. Simulated Annealing (Recocido Simulado)
Esta es la técnica clave para evitar que el sistema se quede atrapado en soluciones mediocres (mínimos locales).
- **T Ini (Alta)**: Al principio, el sistema tiene mucho ruido para explorar muchas combinaciones.
- **T Fin (Baja)**: Al final, el ruido baja para que la red se "congele" en la solución óptima.

## 🛠️ Cómo Utilizarlo

### Requisitos
Necesitas tener instalado Python y las siguientes librerías:
```bash
pip install pyserial numpy dearpygui
```

### Ejecución
En la consola de Anaconda/Spyder o terminal estándar:
```python
%runfile 'pc_client_maxcutV2.py' --wdir
```

### Flujo de Trabajo Recomendado
1. **Configurar Puerto**: Asegúrate de que el `Puerto Serial` coincida con tu Master (ej: `COM16`).
2. **Batch K**: Define cuántas muestras quieres (ej: `500`).
3. **Activar Annealing**: Marca la casilla `Simulated Annealing`.
4. **Parámetros T**: Pon `T Ini: 0.35` y `T Fin: 0.05`.
5. **Iniciar**: Haz clic en **CONECTAR / INICIAR**.
6. **Observar**: Mira el gráfico circular. Verás cómo los colores "bailan" al principio y se estabilizan al final en una configuración de máximo corte.

## 🔄 Botones de Control Especiales
- **REINICIAR MUESTRA**: Limpia todo y vuelve a lanzar el experimento. Ideal para probar cambios rápidos.
- **LIMPIAR ESTADÍSTICAS**: Resetea los gráficos pero mantiene la conexión actual.
- **GUARDAR CSV**: Exporta todos los datos recolectados a un archivo para análisis posterior en Excel o Python.

---
> [!TIP]
> Si el sistema no llega al 100% de eficiencia, intenta aumentar el valor de **K** (muestras) o el intervalo entre **T Ini** y **T Fin**.

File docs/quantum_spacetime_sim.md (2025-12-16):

# Simulación de sistemas espacio-temporales con la arquitectura I2C

Este documento conecta la plataforma distribuida maestro–esclavos de este
repositorio con ideas modernas de simulación cuántica y la intuición holográfica
propuesta por Juan Maldacena. El objetivo es reutilizar los nodos I2C como
**bloques de procesamiento** que emulen la evolución de un sistema espacio-
tiempo discretizado, manteniendo el maestro como orquestador y agregador de
observables.

## Mapa entre la arquitectura actual y la simulación cuántica

- **Maestro como capa “bulk”**: el nodo maestro ya agrega y temporaliza datos de
  los esclavos, mostrando resultados y registrándolos en SD
  (`master/master.ino`). Esto es análogo a un observador en el volumen (bulk)
  que recopila observables globales.
- **Esclavos como “boundary blocks”**: cada esclavo procesa muestras
  independientes y entrega un paquete compacto por I2C
  (`cuantums/cuantums.ino`). En una analogía AdS/CFT, estos bloques serían
  grados de libertad de la teoría de campos en el borde que codifican la
  información del volumen.
- **Ciclos de sondeo**: el maestro ya implementa intervalos de actualización y
  reintentos de comunicación, lo que puede reinterpretarse como pasos de
  evolución discreta de un hamiltoniano efectivo.
- **Estado del bus como grafo**: las direcciones I2C y el escaneo del bus pueden
  verse como nodos y aristas de un grafo de interacción. Extender el arreglo de
  direcciones permite aumentar la “resolución” espacial del grafo.

## Cómo reutilizar los nodos como bloques de simulación

1. **Codificar variables físicas**: en lugar de conteos de opiniones,
   reinterpretar `favor/contra/neutral` como amplitudes, campos discretizados o
   contadores de eventos (p. ej., ocupación de sitios, número de qubits
   excitados). Para mayor fidelidad, cambiar el formato de payload a valores de
   punto flotante o enteros fijos escalados.
2. **Programar reglas locales**: en cada esclavo, reemplazar `simulateOpinion()`
   por la actualización de un modelo físico (Ising, autómatas celulares
   cuánticos aproximados, circuitos variacionales). El maestro solo requiere
   los resultados agregados por ciclo, por lo que la carga principal reside en
   los nodos.
3. **Sincronizar pasos**: usar el `UPDATE_INTERVAL_MS` como paso de tiempo
   discreto global. Si se necesitan dependencias entre nodos, incluir en el
   payload identificadores de vecino o fases compartidas y que el maestro
   redistribuya parámetros comunes al siguiente ciclo.
4. **Registrar observables**: aprovechar el logger en SD y el display OLED para
   monitorear magnitudes agregadas (energía, magnetización, entropía estimada).
   Mantener la misma ruta de datos simplifica comparar corridas.
5. **Escalabilidad**: añadir más direcciones I2C en `config.h` y programar
   esclavos adicionales para aumentar la granularidad espacial. Verificar el
   ruido y la disipación del bus antes de exceder longitudes físicas de cable.

## Inspiración desde Maldacena y la correspondencia AdS/CFT

- **Principio holográfico aplicado a hardware**: la idea central de Maldacena es
  que una teoría gravitacional en el bulk es dual a una teoría de campos sin
  gravedad en el borde. En esta plataforma, los esclavos (borde) codifican el
  estado global que el maestro (bulk) observa. Ajustar reglas locales que
  preserven información (checksums, corrección de errores) refuerza la analogía
  con códigos holográficos.
- **Geometría emergente**: variar las reglas de acoplamiento entre esclavos (p.
  ej., coeficientes de interacción incluidos en el payload) permite explorar
  cómo métricas efectivas emergen de correlaciones, inspirándose en trabajos de
  redes tensoriales y MERA como modelos de espacio-tiempo emergente.
- **Evaporación de agujeros negros y transferencia de información**: usando el
  canal SD/serie se pueden estudiar balances de entropía y flujos de
  información, similar a los experimentos numéricos que verifican el
  comportamiento unitario propuesto en la paradoja de la información.

## Papers y recursos clave para diseñar la simulación

- J. Maldacena, “The Large N Limit of Superconformal Field Theories and
  Supergravity,” *Adv. Theor. Math. Phys.* 2 (1998) 231–252. Punto de partida de
  la correspondencia AdS/CFT.
- G. ’t Hooft y L. Susskind, trabajos sobre el **principio holográfico**, base
  conceptual de la dualidad.
- B. Swingle, “Entanglement Renormalization and Holography,” *Phys. Rev. D* 86,
  065007 (2012). Relaciona redes tensoriales con geometría emergente.
- F. Pastawski, B. Yoshida, D. Harlow, J. Preskill, “Holographic quantum
  error-correcting codes: Toy models for the bulk/boundary correspondence,”
  *JHEP* 06 (2015) 149. Ilustra cómo la corrección de errores implementa el
  principio holográfico.
- P. Hayden, J. Preskill, “Black holes as mirrors,” *JHEP* 09 (2007) 120.
  Referencia clásica sobre recuperación de información.
- S. Lloyd et al., “Quantum algorithms for simulating gauge theories,” y M.
  Biamonte et al., “Quantum Machine Learning,” como guías para mapear modelos
  físicos a circuitos cuánticos o simuladores híbridos.

## Pasos sugeridos para una primera implementación

1. Definir una magnitud física simple (p. ej., magnetización Ising 1D) y mapearla
   a los tres contadores de cada esclavo.
2. Ajustar el payload a números enteros escalados y documentar el factor de
   escala.
3. Usar el maestro como recolector y visualizador de observables; mantener un
   script externo que procese `datalog.csv` para graficar correlaciones.
4. Iterar agregando más nodos para mejorar la resolución espacial y probar reglas
   de acoplamiento dependientes de vecinos.

> Esta aproximación no convierte el hardware en un computador cuántico, pero
> permite prototipar algoritmos de inspiración holográfica y modelos de dinámica
> espacio-temporal distribuida con hardware accesible.

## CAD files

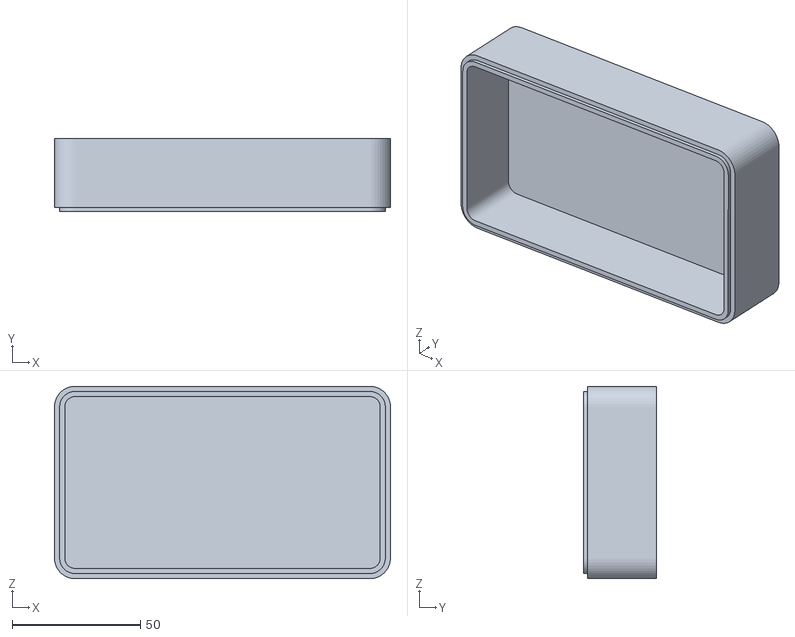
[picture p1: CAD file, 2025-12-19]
modelo_3d_cuantum32/tapacuantum.stl
131.0 x 28.5 x 75.0

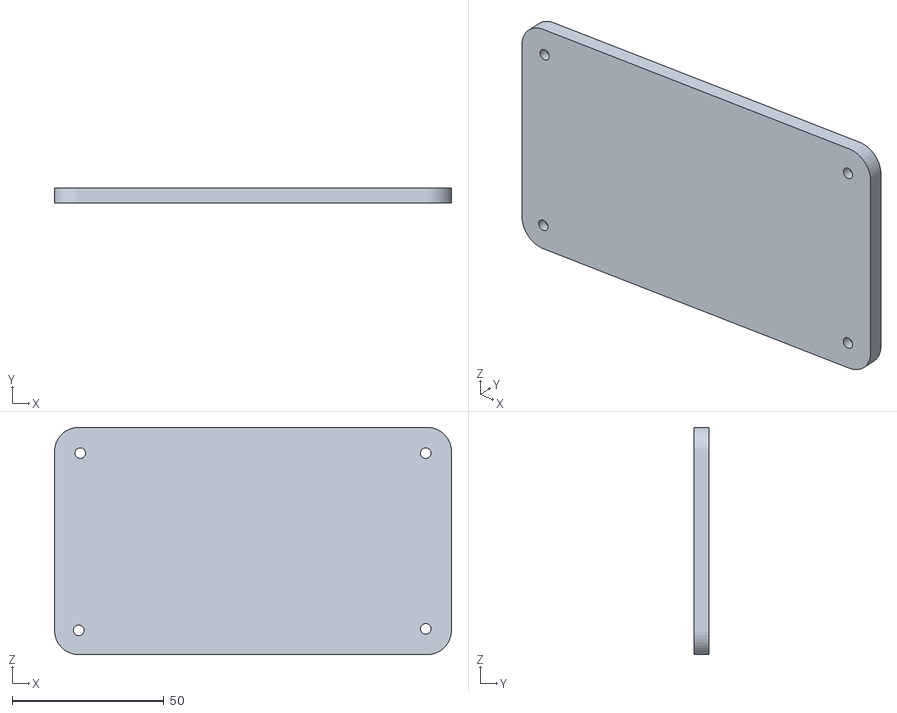
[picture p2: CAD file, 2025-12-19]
modelo_3d_cuantum32/basecuantum.stl
131.0 x 5.00 x 75.0

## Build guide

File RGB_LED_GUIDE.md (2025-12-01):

# LED RGB Addressable - Guía de Uso

## 📍 Configuración

### Hardware
- **LED**: WS2812B / NeoPixel (addressable RGB LED)
- **Pin**: GPIO 48 (ESP32 S3 Super Mini)
- **Cantidad**: 1 LED (configurable hasta múltiples LEDs)
- **Voltaje**: 5V (puede funcionar con 3.3V pero con colores menos brillantes)

### Conexión
```
LED RGB (WS2812B)
├── VCC  → 5V (o 3.3V)
├── GND  → GND
└── DIN  → GPIO 48
```

## 🎨 Códigos de Color

| Color | Estado | Significado |
|---|---|---|
| 🔵 **Azul** | Idle | Esperando próximo ciclo de lectura |
| 🟡 **Amarillo** | Reading | Leyendo datos de slaves |
| 🟢 **Verde** | Success | Todos los slaves respondieron OK |
| 🟠 **Naranja** | Warning | Algunos slaves no respondieron |
| 🔴 **Rojo** | Error | Ningún slave respondió |

## 🔄 Secuencia de Operación

```
1. AZUL (Idle)
   ↓
2. AMARILLO (Leyendo slaves...)
   ↓
3. VERDE/NARANJA/ROJO (según resultado)
   ↓
4. Espera UPDATE_INTERVAL_MS
   ↓
5. Volver a AZUL
```

## 📺 Indicadores en Pantalla OLED

La pantalla OLED ahora muestra el estado de cada slave en la esquina superior derecha:

```
OPINION ANALYSIS    Slaves: OK OK X OK
─────────────────────────────────────
Time: 12:45:32

A favor  : 42.3%
En contra: 35.8%
Dudando  : 21.9%
```

- **OK** = Slave respondió correctamente
- **X** = Slave no respondió o error

## ⚙️ Configuración en config.h

```cpp
// Habilitar/deshabilitar LED RGB
#define ENABLE_RGB_LED    true

// Pin del LED
#define RGB_LED_PIN       48

// Número de LEDs (si tienes una tira)
#define NUM_RGB_LEDS      1

// Personalizar colores (R, G, B: 0-255)
#define RGB_COLOR_IDLE      0, 0, 50      // Azul
#define RGB_COLOR_READING   255, 255, 0   // Amarillo
#define RGB_COLOR_SUCCESS   0, 255, 0     // Verde
#define RGB_COLOR_WARNING   255, 128, 0   // Naranja
#define RGB_COLOR_ERROR     255, 0, 0     // Rojo
```

## 🔧 Ajustes de Brillo

En `master.ino`, línea ~113:
```cpp
rgbLed.setBrightness(50);  // 0-255 (50 = ~20% brillo)
```

Valores recomendados:
- **25**: Muy tenue (ideal para uso nocturno)
- **50**: Tenue (recomendado, ahorra energía)
- **100**: Medio
- **255**: Máximo brillo (consume más corriente)

## 🐛 Troubleshooting

### LED no enciende
1. Verificar conexión VCC y GND
2. Verificar pin correcto (GPIO 48)
3. Verificar que `ENABLE_RGB_LED` está en `true`
4. Probar con ejemplo básico de NeoPixel

### Colores incorrectos
1. Verificar tipo de LED en código:
   ```cpp
   // Para WS2812B (más común)
   Adafruit_NeoPixel rgbLed(NUM_RGB_LEDS, RGB_LED_PIN, NEO_GRB + NEO_KHZ800);
   
   // Si los colores están invertidos, probar:
   Adafruit_NeoPixel rgbLed(NUM_RGB_LEDS, RGB_LED_PIN, NEO_RGB + NEO_KHZ800);
   ```

2. Ajustar valores RGB en `config.h`

### LED parpadea erráticamente
1. Reducir brillo: `rgbLed.setBrightness(25);`
2. Agregar capacitor 100µF entre VCC y GND del LED
3. Verificar fuente de alimentación estable

## 📊 Ejemplo de Uso

### Monitoreo Visual Rápido
Sin necesidad de abrir Serial Monitor, puedes saber el estado del sistema:

- **🔵 Parpadeando cada 1.5s** = Sistema funcionando normalmente
- **🟢 Constante** = Todos los slaves OK
- **🟠 Constante** = Algunos slaves fallando (revisar OLED para ver cuáles)
- **🔴 Constante** = Sistema sin comunicación con slaves

### Debug en Pantalla OLED
La pantalla muestra exactamente qué slaves están respondiendo:
```
Slaves: OK OK X OK
         ↑  ↑ ↑ ↑
         1  2 3 4
```
En este ejemplo, el Slave 3 (0x12) no está respondiendo.

## 🎯 Ventajas

1. **Feedback visual inmediato** sin necesidad de Serial Monitor
2. **Debug rápido** viendo qué slaves fallan en la OLED
3. **Sincronización visible** - el LED amarillo muestra cuándo se están leyendo datos
4. **Estado del sistema** de un vistazo

## 📝 Notas

- El LED consume ~20mA a brillo medio (50)
- Si usas múltiples LEDs (`NUM_RGB_LEDS > 1`), considera fuente externa de 5V
- El LED se actualiza en cada ciclo de lectura (cada `UPDATE_INTERVAL_MS`)

---

**LED RGB configurado y funcionando** ✅

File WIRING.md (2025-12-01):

# Guía de Conexiones - Sistema I2C Multi-Slave

Esta guía detalla las conexiones de hardware para el sistema de análisis de opiniones distribuido.

## 📌 Conceptos Básicos I2C

El bus I2C (Inter-Integrated Circuit) es un protocolo de comunicación serial que utiliza solo 2 cables:
- **SDA** (Serial Data): Línea de datos bidireccional
- **SCL** (Serial Clock): Línea de reloj generada por el maestro

### Características Importantes
- Todos los dispositivos comparten las mismas líneas SDA y SCL
- Cada dispositivo tiene una dirección única (7 bits)
- Se requieren resistencias pull-up en ambas líneas
- Máximo de 127 dispositivos en un bus (teóricamente)

## 🔌 Pines I2C por Placa Arduino

| Placa Arduino | SDA Pin | SCL Pin |
|---|---|---|
| Uno / Nano | A4 | A5 |
| Mega 2560 | 20 | 21 |
| Leonardo | 2 | 3 |
| ESP32 | 21 | 22 |
| ESP8266 | GPIO4 (D2) | GPIO5 (D1) |

> [!NOTE]
> Algunos microcontroladores permiten configurar pines I2C alternativos. Consulta la documentación de tu placa.

## 🔧 Esquema de Conexión General

```
                    +5V (o 3.3V)
                     |
                     |
        4.7kΩ        |        4.7kΩ
    ┌────────────────┼────────────────┐
    |                |                |
    |                |                |
   SDA              GND              SCL
    |                                 |
    |─────────────────────────────────|
    |                                 |
    |    ┌──────────┐                 |
    ├────┤  MASTER  ├─────────────────┤
    |    └──────────┘                 |
    |                                 |
    |    ┌──────────┐                 |
    ├────┤ SLAVE 1  ├─────────────────┤
    |    │ (0x10)   │                 |
    |    └──────────┘                 |
    |                                 |
    |    ┌──────────┐                 |
    ├────┤ SLAVE 2  ├─────────────────┤
    |    │ (0x11)   │                 |
    |    └──────────┘                 |
    |                                 |
    |    ┌──────────┐                 |
    ├────┤ SLAVE 3  ├─────────────────┤
    |    │ (0x12)   │                 |
    |    └──────────┘                 |
    |                                 |
    |    ┌──────────┐                 |
    ├────┤ SLAVE 4  ├─────────────────┤
    |    │ (0x13)   │                 |
    |    └──────────┘                 |
    |                                 |
    |    ┌──────────┐                 |
    ├────┤   OLED   ├─────────────────┤
    |    │ (0x3C)   │                 |
    |    └──────────┘                 |
    |                                 |
    |    ┌──────────┐                 |
    └────┤   RTC    ├─────────────────┘
         │ (0x68)   │
         └──────────┘
```

## 📋 Conexiones Detalladas

### Maestro (Master Arduino)

#### Conexiones I2C
| Pin Master | Conectar a |
|---|---|
| SDA | Bus SDA común (con pull-up 4.7kΩ a VCC) |
| SCL | Bus SCL común (con pull-up 4.7kΩ a VCC) |
| GND | GND común de todos los dispositivos |
| 5V o 3.3V | Alimentación (compartida si es posible) |

#### OLED Display (1.3" SH1106)
| Pin OLED | Conectar a |
|---|---|
| VCC | 3.3V o 5V (según modelo) |
| GND | GND común |
| SDA | Bus SDA |
| SCL | Bus SCL |

#### RTC DS3231
| Pin RTC | Conectar a |
|---|---|
| VCC | 5V (o 3.3V según modelo) |
| GND | GND común |
| SDA | Bus SDA |
| SCL | Bus SCL |

### Esclavos (Slave Arduinos)

Cada esclavo se conecta de manera idéntica:

| Pin Slave | Conectar a |
|---|---|
| SDA | Bus SDA común |
| SCL | Bus SCL común |
| GND | GND común |
| 5V o 3.3V | Alimentación |

> [!IMPORTANT]
> **Cada esclavo debe programarse con una dirección I2C única** (0x10, 0x11, 0x12, 0x13, etc.)

## ⚡ Resistencias Pull-Up

### ¿Por qué son necesarias?
Las líneas I2C son de "drenaje abierto", lo que significa que los dispositivos solo pueden llevar la línea a GND. Las resistencias pull-up son necesarias para llevar las líneas a nivel alto (VCC).

### Valores Recomendados
- **4.7kΩ**: Valor estándar para la mayoría de aplicaciones
- **2.2kΩ**: Para buses largos o alta velocidad
- **10kΩ**: Para buses cortos con pocos dispositivos

### Ubicación
Instalar **una sola vez** en el bus:
```
VCC (5V o 3.3V)
 |
 ├── 4.7kΩ ──┬── SDA (a todos los dispositivos)
 |           |
 └── 4.7kΩ ──┴── SCL (a todos los dispositivos)
```

> [!WARNING]
> **No duplicar pull-ups**: Algunos módulos (como OLED o RTC) pueden incluir resistencias pull-up integradas. Si tienes problemas de comunicación, verifica con un multímetro.

## 🔋 Consideraciones de Alimentación

### Voltaje
- **5V**: Arduino Uno, Mega, Nano (5V)
- **3.3V**: ESP32, ESP8266, Arduino Due

> [!CAUTION]
> **Mezclar voltajes**: Si mezclas dispositivos de 3.3V y 5V, usa un convertidor de nivel lógico (level shifter) para proteger los dispositivos de 3.3V.

### Consumo de Corriente
Estimación aproximada:
- Arduino Uno/Nano: ~50mA
- OLED Display: ~20mA
- RTC DS3231: ~1mA
- **Total para 1 master + 4 slaves**: ~300mA

Recomendación: Usar fuente de alimentación de al menos **1A** para estabilidad.

### Distribución de Alimentación
Para múltiples dispositivos:
1. **Opción 1**: Alimentar todos desde una fuente externa común
2. **Opción 2**: Alimentar el master desde USB y los slaves desde fuente externa (conectar GND común)

## 📏 Longitud de Cables

| Longitud | Velocidad I2C | Notas |
|---|---|---|
| < 1 metro | 400 kHz | Sin problemas |
| 1-3 metros | 100 kHz | Reducir velocidad |
| > 3 metros | < 100 kHz | Usar cables apantallados |

> [!TIP]
> Para cables largos, reduce la velocidad I2C en `config.h`:
> ```cpp
> #define I2C_CLOCK_SPEED 50000  // 50 kHz para cables largos
> ```

## 🧪 Verificación de Conexiones

### 1. Verificar Continuidad
Con un multímetro en modo continuidad:
- Verificar que todos los SDA están conectados
- Verificar que todos los SCL están conectados
- Verificar GND común

### 2. Verificar Pull-Ups
Con multímetro en modo resistencia:
- Entre SDA y VCC: debe leer ~4.7kΩ
- Entre SCL y VCC: debe leer ~4.7kΩ

### 3. Escaneo I2C
Cargar el siguiente sketch en el master para escanear dispositivos:

```cpp
#include <Wire.h>

void setup() {
  Serial.begin(115200);
  Wire.begin();
  Serial.println("Escaneando bus I2C...");
  
  for (byte addr = 1; addr < 127; addr++) {
    Wire.beginTransmission(addr);
    if (Wire.endTransmission() == 0) {
      Serial.print("Dispositivo en 0x");
      Serial.println(addr, HEX);
    }
  }
  Serial.println("Escaneo completo");
}

void loop() {}
```

Deberías ver:
- `0x3C` o `0x3D` - OLED
- `0x68` - RTC
- `0x10`, `0x11`, `0x12`, `0x13` - Slaves

## 🛠️ Solución de Problemas de Conexión

### No se detectan dispositivos
1. ✅ Verificar alimentación de todos los dispositivos
2. ✅ Confirmar resistencias pull-up instaladas
3. ✅ Revisar continuidad de SDA y SCL
4. ✅ Verificar GND común conectado

### Comunicación intermitente
1. ✅ Reducir velocidad I2C a 100 kHz o menos
2. ✅ Acortar cables
3. ✅ Verificar valor de pull-ups (probar 2.2kΩ)
4. ✅ Revisar fuente de alimentación (debe ser estable)

### Conflictos de dirección
1. ✅ Usar sketch de escaneo para identificar direcciones
2. ✅ Verificar que cada slave tiene dirección única
3. ✅ Confirmar que no hay duplicados

## 📸 Ejemplo de Montaje en Protoboard

Para un montaje limpio:
1. Colocar las resistencias pull-up cerca del master
2. Usar cables de colores:
   - **Rojo**: VCC/5V
   - **Negro**: GND
   - **Amarillo**: SDA
   - **Verde**: SCL
3. Mantener cables cortos y organizados
4. Etiquetar cada slave con su dirección I2C

---

**¿Necesitas ayuda?** Abre un issue en el repositorio de GitHub con fotos de tu montaje.

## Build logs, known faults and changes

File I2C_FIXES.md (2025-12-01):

# Corrección de Problemas I2C - Cuantums

## ✅ Problemas Identificados y Corregidos

### Problema 1: Doble inicialización de Wire en Slave
**Error**: `Wire.begin()` llamado dos veces con parámetros diferentes
```cpp
// ❌ ANTES (líneas 55 y 66)
Wire.begin(SDAPIN, SCLPIN);  // Primera llamada
...
Wire.begin(SLAVE_ADDRESS);   // Segunda llamada - conflicto!
```

**Solución**: Una sola inicialización con todos los parámetros
```cpp
// ✅ AHORA
Wire.begin(SLAVE_ADDRESS, SDAPIN, SCLPIN);  // ESP32 format
```

### Problema 2: Protocolo I2C incompatible
**Error**: Slave enviaba buffer binario, pero el patrón funcional usa String

**Código que funcionaba** (sensor SO₂/TVOC):
```cpp
String payload = String(sensor1.pVgas, 3) + "," + String(vocConcentration) + "\n";
Wire.write(payload.c_str());
```

**Solución aplicada**:
```cpp
// Slave envía CSV string
String payload = String(favorCount) + "," + String(contraCount) + "," + String(neutralCount) + "\n";
Wire.write(payload.c_str());

// Master lee y parsea CSV
String response = "";
while (Wire.available()) {
  char c = Wire.read();
  if (c == '\n') break;
  response += c;
}
// Parse: "123,456,789"
```

### Problema 3: delay() en ISR
**Error**: `delay(10)` dentro de `requestEvent()` puede causar problemas
```cpp
// ❌ ANTES
void requestEvent() {
  Wire.write(buffer, 6);
  digitalWrite(LED_PIN, HIGH);
  delay(10);  // ¡NO hacer delay() en ISR!
  digitalWrite(LED_PIN, LOW);
}
```

**Solución**: Manejo no bloqueante del LED
```cpp
// ✅ AHORA
void requestEvent() {
  Wire.write(payload.c_str());
  digitalWrite(LED_PIN, HIGH);
  // LED se apaga en loop() principal
}

void loop() {
  if (digitalRead(LED_PIN) == HIGH && (millis() - ledOffTime > 10)) {
    digitalWrite(LED_PIN, LOW);
  }
}
```

## 📝 Cambios Realizados

### cuantums/cuantums.ino (Slave)
1. ✅ Corregida inicialización I2C para ESP32
2. ✅ Cambiado protocolo de buffer binario a String CSV
3. ✅ Eliminado `delay()` de `requestEvent()`
4. ✅ Agregado manejo no bloqueante de LED

### master/master.ino (Master)
1. ✅ Actualizado `requestDataFromSlave()` para leer String CSV
2. ✅ Agregado parsing de formato "favor,contra,neutral\n"
3. ✅ Aumentado buffer de lectura a 32 bytes
4. ✅ Agregado logging de respuestas recibidas

## 🔧 Configuración Actual

### Slave (cuantums.ino)
```cpp
#define SLAVE_ADDRESS 0x10
#define SDAPIN 5
#define SCLPIN 6
#define LED_PIN 8
```

### Master (master.ino)
```cpp
// En config.h
const uint8_t SLAVE_ADDRESSES[] = {0x10, 0x11, 0x12, 0x13};
```

## 🧪 Pruebas Recomendadas

1. **Probar con 1 slave primero**
   - Cargar `cuantums.ino` con `SLAVE_ADDRESS 0x10`
   - Verificar en Serial Monitor del slave que se inicializa
   - Verificar en Serial Monitor del master que detecta 0x10

2. **Verificar comunicación**
   - Master debe mostrar: `Received from 0x10: 123,456,789`
   - Slave debe mostrar: `Data sent to master: 123, 456, 789`

3. **Agregar más slaves**
   - Cambiar `SLAVE_ADDRESS` a 0x11, 0x12, 0x13
   - Cargar en cada Arduino
   - Verificar que master agrega correctamente

## ⚠️ Notas Importantes

### Para ESP32
- Los pines I2C por defecto en ESP32 S3 Super Mini son:
  - SDA = Pin 8
  - SCL = Pin 9
- Si usas otros pines, ajusta `SDAPIN` y `SCLPIN`

### Para Arduino Uno/Nano
- Cambiar inicialización a:
```cpp
Wire.begin(SLAVE_ADDRESS);  // Sin especificar pines
```

### Resistencias Pull-up
- Asegúrate de tener 4.7kΩ en SDA y SCL
- Sin pull-ups, la comunicación I2C fallará

## 🐛 Debugging

Si sigue sin funcionar:

1. **Verificar escaneo I2C**
   ```
   Device found at 0x10 (Slave Device)
   ```

2. **Verificar Serial del Slave**
   ```
   === I2C Slave - Opinion Analysis Worker ===
   I2C Address: 0x10
   Slave ready and waiting for master requests...
   ```

3. **Verificar Serial del Master**
   ```
   Received from 0x10: 102,89,65
   ```

4. **Si no hay comunicación**
   - Verificar conexiones SDA/SCL
   - Verificar GND común
   - Verificar pull-ups
   - Probar con I2C scanner

---

**Cambios aplicados exitosamente** ✅

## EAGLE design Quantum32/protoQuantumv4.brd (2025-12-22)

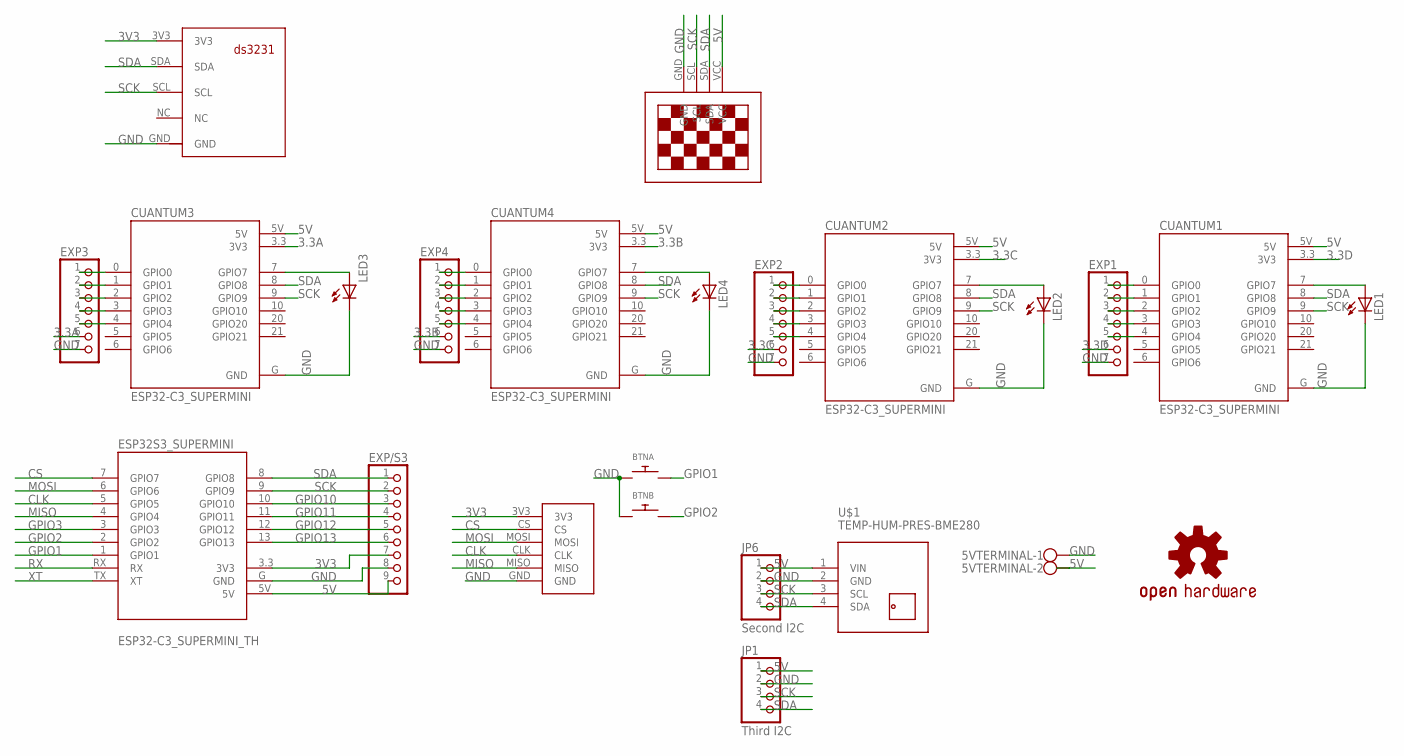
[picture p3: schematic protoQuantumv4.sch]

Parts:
5VTERMINAL: W237-102
BTNA: SWITCH_PUSHBUTTONEVQ-PE; TACT_PANA-EVQ
BTNB: SWITCH_PUSHBUTTONEVQ-PE; TACT_PANA-EVQ
CUANTUM1, CUANTUM2, CUANTUM3, CUANTUM4: ESP32-C3_SUPERMINI; MODULE_ESP32-C3_SUPERMINI_TH
ESP32S3_SUPERMINI: ESP32-C3_SUPERMINI_TH; MODULE_ESP32-C3_SUPERMINI_TH
EXP1, EXP2, EXP3, EXP4: PINHD-1X7; 1X07
EXP/S3: PINHD-1X9; 1X09
JP1: Third I2C; 1X04
JP6: Second I2C; 1X04
LED1, LED2, LED3, LED4: LED3MM
LOGO1: OSHW-LOGOM; OSHW-LOGO-M
OLED1.3: 13"OLED13"OLED; 1.3"OLED
U$1: TEMP-HUM-PRES-BME280
U$2: SD_KUSKALLA
U$4: RTC; RTCDS3231FP

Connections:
3.3A: CUANTUM3.3.3 (3V3), EXP3.6
3.3B: CUANTUM4.3.3 (3V3), EXP4.6
3.3C: CUANTUM2.3.3 (3V3), EXP2.6
3.3D: CUANTUM1.3.3 (3V3), EXP1.6
3V3: ESP32S3_SUPERMINI.3.3 (3V3), EXP/S3.7, U$2.3V3, U$4.3V3
5V: 5VTERMINAL.2, CUANTUM1.5V, CUANTUM2.5V, CUANTUM3.5V, CUANTUM4.5V, ESP32S3_SUPERMINI.5V, EXP/S3.9, JP1.1, JP6.1, OLED1.3.VCC, U$1.1 (VIN)
CLK: ESP32S3_SUPERMINI.5 (GPIO5), U$2.CLK
CS: ESP32S3_SUPERMINI.7 (GPIO7), U$2.CS
GND: 5VTERMINAL.1, BTNA.P$1, BTNB.P$1, CUANTUM1.G (GND), CUANTUM2.G (GND), CUANTUM3.G (GND), CUANTUM4.G (GND), ESP32S3_SUPERMINI.G (GND), EXP1.7, EXP2.7, EXP3.7, EXP4.7, EXP/S3.8, JP1.2, JP6.2, LED1.K (C), LED2.K (C), LED3.K (C), LED4.K (C), OLED1.3.GND, U$1.2 (GND), U$2.GND, U$4.GND
GPIO1: BTNA.P$2, ESP32S3_SUPERMINI.1 (GPIO1)
GPIO2: BTNB.P$2, ESP32S3_SUPERMINI.2 (GPIO2)
GPIO3: ESP32S3_SUPERMINI.3 (GPIO3)
GPIO10: ESP32S3_SUPERMINI.10 (GPIO10), EXP/S3.3
GPIO11: ESP32S3_SUPERMINI.11 (GPIO11), EXP/S3.4
GPIO12: ESP32S3_SUPERMINI.12 (GPIO12), EXP/S3.5
GPIO13: ESP32S3_SUPERMINI.13 (GPIO13), EXP/S3.6
MISO: ESP32S3_SUPERMINI.4 (GPIO4), U$2.MISO
MOSI: ESP32S3_SUPERMINI.6 (GPIO6), U$2.MOSI
unnamed: CUANTUM4.7 (GPIO7), LED4.A
unnamed: CUANTUM4.0 (GPIO0), EXP4.1
unnamed: CUANTUM3.7 (GPIO7), LED3.A
unnamed: CUANTUM1.0 (GPIO0), EXP1.1
unnamed: CUANTUM1.1 (GPIO1), EXP1.2
unnamed: CUANTUM2.7 (GPIO7), LED2.A
unnamed: CUANTUM1.7 (GPIO7), LED1.A
unnamed: CUANTUM3.0 (GPIO0), EXP3.1
unnamed: CUANTUM3.1 (GPIO1), EXP3.2
unnamed: CUANTUM3.2 (GPIO2), EXP3.3
unnamed: CUANTUM3.3 (GPIO3), EXP3.4
unnamed: CUANTUM3.4 (GPIO4), EXP3.5
unnamed: CUANTUM4.1 (GPIO1), EXP4.2
unnamed: CUANTUM4.2 (GPIO2), EXP4.3
unnamed: CUANTUM4.3 (GPIO3), EXP4.4
unnamed: CUANTUM4.4 (GPIO4), EXP4.5
unnamed: CUANTUM2.0 (GPIO0), EXP2.1
unnamed: CUANTUM2.1 (GPIO1), EXP2.2
unnamed: CUANTUM2.2 (GPIO2), EXP2.3
unnamed: CUANTUM2.3 (GPIO3), EXP2.4
unnamed: CUANTUM2.4 (GPIO4), EXP2.5
unnamed: CUANTUM1.2 (GPIO2), EXP1.3
unnamed: CUANTUM1.3 (GPIO3), EXP1.4
unnamed: CUANTUM1.4 (GPIO4), EXP1.5
RX: ESP32S3_SUPERMINI.RX
SCK: CUANTUM1.9 (GPIO9), CUANTUM2.9 (GPIO9), CUANTUM3.9 (GPIO9), CUANTUM4.9 (GPIO9), ESP32S3_SUPERMINI.9 (GPIO9), EXP/S3.2, JP1.3, JP6.3, OLED1.3.SCL, U$1.3 (SCL), U$4.SCL
SDA: CUANTUM1.8 (GPIO8), CUANTUM2.8 (GPIO8), CUANTUM3.8 (GPIO8), CUANTUM4.8 (GPIO8), ESP32S3_SUPERMINI.8 (GPIO8), EXP/S3.1, JP1.4, JP6.4, OLED1.3.SDA, U$1.4 (SDA), U$4.SDA
XT: ESP32S3_SUPERMINI.TX (XT)

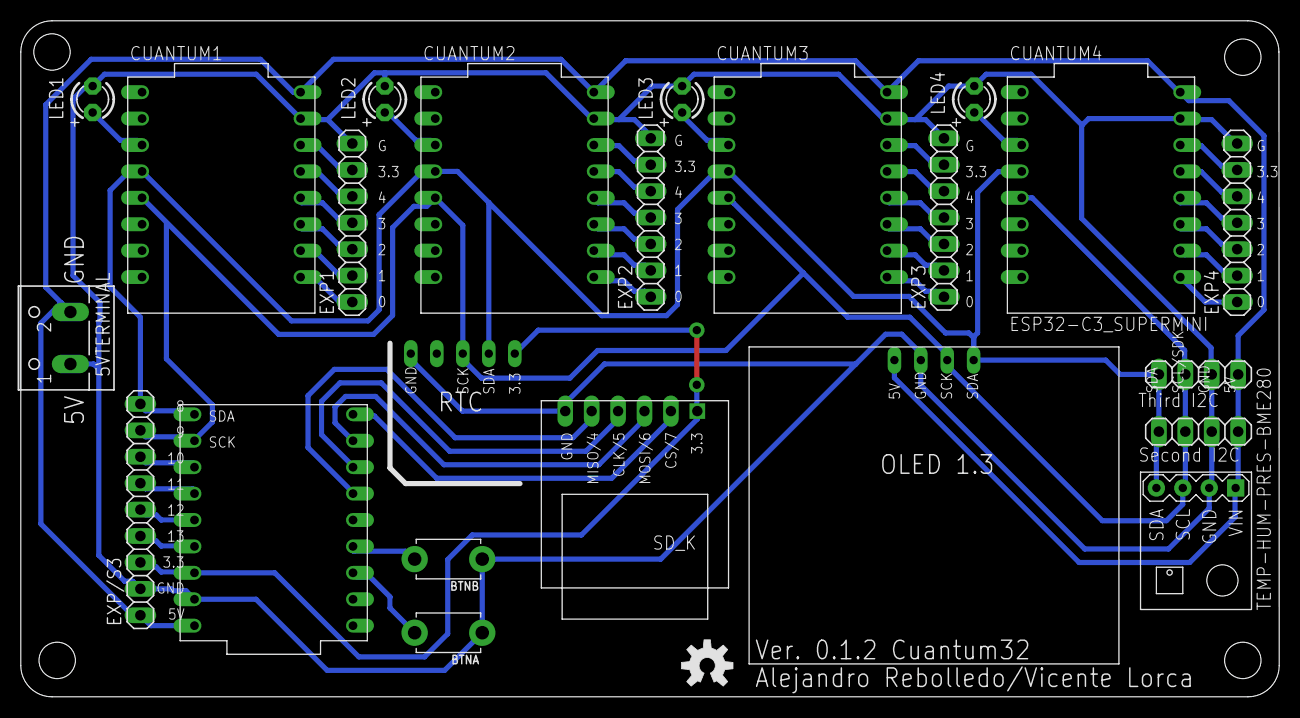
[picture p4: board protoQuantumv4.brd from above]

Board: 2 copper layers, 121.0 x 65.0 mm, 24 parts (0 on the bottom side), 43 nets.

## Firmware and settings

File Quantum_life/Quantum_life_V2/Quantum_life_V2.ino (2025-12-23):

/* Cuantum Life V2.3.1 — Balanced Holographic Core
 *
 * Fixes vs V2.2:
 * - I2C tick is now independent from Game-of-Life generation (no more expected-tick mismatch).
 * - Non-blocking I2C polling breathers (no delay(4) in the core scheduler).
 * - Health reporting with flags + per-slave status.
 * - Robust retries for BME/SD (no abort in setup).
 * - Non-blocking button handling (no while() wait loops).
 *
 * Hardware (as provided):
 *   BTNA=2, BTNB=1, LED=48, SD(HSPI)=7,6,4,5.
 *
 * Notes:
 * - Keeps your GOL engine + OLED rendering.
 * - Keeps hybrid slave parsing (LONG + COMPACT).
 * - Uses global flags and logs in loop().
 */

#include <Wire.h>
#include <U8g2lib.h>
#include <RTClib.h>
#include <Adafruit_NeoPixel.h>
#include <Adafruit_Sensor.h>
#include <Adafruit_BME280.h>
#include "FS.h"
#include "SD.h"
#include "SPI.h"
#include <esp_random.h>
#include <math.h>

// ============================================================================
// CONFIGURATION & PINS
// ============================================================================
static constexpr int BTNA_PIN = 2;
static constexpr int BTNB_PIN = 1;
static constexpr int RGB_LED_PIN = 48;

// SD (HSPI)
static constexpr int SD_CS_PIN   = 7;
static constexpr int SD_MOSI_PIN = 6;
static constexpr int SD_MISO_PIN = 4;
static constexpr int SD_SCLK_PIN = 5;

// I2C Addresses
static constexpr uint8_t OLED_ADDR = 0x3C;
static constexpr uint8_t BME_ADDR  = 0x76;
static constexpr uint8_t SLAVE_ADDRESSES[] = { 0x10, 0x11, 0x12, 0x13 };
static constexpr uint8_t NUM_SLAVES = sizeof(SLAVE_ADDRESSES) / sizeof(SLAVE_ADDRESSES[0]);

// I2C Settings
static constexpr uint32_t I2C_CLOCK_SPEED  = 100000;
static constexpr uint16_t I2C_TIMEOUT_MS   = 200;
static constexpr uint8_t  I2C_MAX_RX_BYTES = 32;

// Timing (Non-blocking)
static constexpr uint32_t TICK_PERIOD_MS   = 1500;   // I2C tick period
static constexpr uint32_t FRAME_TIME_MS    = 35;     // GOL evolution
static constexpr uint32_t RETRY_PERIOD_MS  = 10000;  // HW retry
static constexpr uint32_t HEALTH_PERIOD_MS = 2000;   // Serial health report
static constexpr uint32_t I2C_BREATHER_MS  = 4;      // gap between slave polls

// Buttons
static constexpr uint32_t BTN_SHORT_MS = 1000;
static constexpr uint32_t BTN_LONG_MS  = 2000;

// ============================================================================
// MODULES & GLOBALS
// ============================================================================
U8G2_SH1106_128X64_NONAME_F_HW_I2C u8g2(U8G2_R0, U8X8_PIN_NONE);
Adafruit_NeoPixel rgbLed(1, RGB_LED_PIN, NEO_GRB + NEO_KHZ800);
Adafruit_BME280 bme;
SPIClass spiSD(HSPI);

// Global flags (no abort)
static bool i2cOK = false;
static bool bmeOK = false;
static bool sdOK  = false;
static bool oledOK = false;

// ============================================================================
// GAME STATE
// ============================================================================
static uint64_t board[128];
static int currentScale = 1; // 1=128x64, 2=64x32

// Game generation (visual evolution) — independent from I2C tick
static uint32_t generation = 0;
static uint32_t population = 0;
static float ambientTemp = 21.0f;
static float globalInjProb = 0.10f;
static bool frozenState = false;

// Loop Detection
#define HASH_BUF_SIZE 32
static uint32_t hashHistory[HASH_BUF_SIZE];
static uint8_t hashIdx = 0;
static bool loopDetected = false;
static uint32_t loopStartTime = 0;

// Simulation Params (shared with slaves)
static float globalNoise = 0.05f;
static int8_t globalBias = 0; // kept for future
static uint8_t globalKp = 0;  // kept for future
static uint8_t simMode = 1;

// ============================================================================
// I2C TICK STATE (robust, independent from GOL generation)
// ============================================================================
static uint32_t tickCounter = 0;  // increments only when starting new I2C tick
static uint32_t activeTick = 0;   // snapshot used for expected parsing
static bool tickInProgress = false;
static uint8_t pollIndex = 0;
static uint32_t lastTickMs = 0;
static uint32_t lastPollStepMs = 0;

// Periodics
static uint32_t nextFrameMs = 0;
static uint32_t nextRetryMs = 0;
static uint32_t lastHealthMs = 0;

// ============================================================================
// SLAVE DATA
// ============================================================================
struct SlaveObs {
  uint32_t tick = 0;
  uint16_t bmask = 0;
  uint16_t loss = 0;
  float noise = NAN;
  uint8_t fmt = 0; // 0=invalid, 1=long, 2=compact
  bool valid = false;
  bool wasValid = false;
  uint32_t lastRxMs = 0;
};

static SlaveObs slaves[NUM_SLAVES];

// ============================================================================
// LED UTILS
// ============================================================================
static void setLed(uint8_t r, uint8_t g, uint8_t b) {
  rgbLed.setPixelColor(0, rgbLed.Color(r, g, b));
  rgbLed.show();
}

// ============================================================================
// INIT HELPERS (NEVER ABORT)
// ============================================================================
static void initI2C() {
  Wire.begin();
  Wire.setClock(I2C_CLOCK_SPEED);
  Wire.setTimeOut(I2C_TIMEOUT_MS);
  i2cOK = true;
}

static void initOLED() {
  if (!oledOK) {
    u8g2.begin();
    oledOK = true;
  }
}

static void initBME() {
  if (!bmeOK) {
    if (bme.begin(BME_ADDR)) {
      bmeOK = true;
      Serial.println("[BME] OK");
    } else {
      Serial.println("[BME] Init failed");
    }
  }
}

static void initSD() {
  if (!sdOK) {
    spiSD.begin(SD_SCLK_PIN, SD_MISO_PIN, SD_MOSI_PIN, SD_CS_PIN);
    if (SD.begin(SD_CS_PIN, spiSD)) {
      sdOK = true;
      Serial.println("[SD] OK");
    } else {
      Serial.println("[SD] Init failed");
    }
  }
}

// ============================================================================
// I2C PROTOCOL (HYBRID: LONG + COMPACT)
// ============================================================================
static inline float clamp01(float x) {
  if (x < 0.0f) return 0.0f;
  if (x > 1.0f) return 1.0f;
  return x;
}

static void sendTickToSlave(uint8_t addr, uint32_t tick) {
  char msg[32];
  snprintf(msg, sizeof(msg), "T,%lu,%u,%.2f\n",
           (unsigned long)tick, (unsigned)simMode, (double)clamp01(globalNoise));

  Wire.beginTransmission(addr);
  Wire.write((const uint8_t*)msg, (uint8_t)strlen(msg));
  uint8_t err = Wire.endTransmission();

  if (err != 0) {
    Serial.printf("[I2C] TX err=%u addr=0x%02X\n", (unsigned)err, (unsigned)addr);
  }
}

static bool parseCompact(const char* buf,
                         uint32_t expectedTick,
                         uint32_t* t,
                         uint16_t* b,
                         uint16_t* l,
                         uint8_t* nB) {
  // "O,%08lX,%04X,%04X,%02X"
  char p = 0;
  unsigned long th = 0;
  unsigned int bh = 0, lh = 0, nh = 0;

  int ok = sscanf(buf, " %c,%lx,%x,%x,%x", &p, &th, &bh, &lh, &nh);
  if (ok < 5 || p != 'O') return false;
  if ((uint32_t)th != expectedTick) return false;

  *t = (uint32_t)th;
  *b = (uint16_t)(bh & 0xFFFFu);
  *l = (uint16_t)(lh & 0xFFFFu);
  *nB = (uint8_t)(nh & 0xFFu);
  return true;
}

static bool parseLong(const char* buf,
                      uint32_t expectedTick,
                      uint32_t* t,
                      uint16_t* b,
                      uint16_t* l,
                      float* n) {
  // "O,<tick>,<bmask>,<loss>,<noise>,<seed>"
  char p = 0;
  unsigned long th = 0;
  unsigned int bh = 0, lh = 0;
  float nf = 0.0f;
  unsigned long seed = 0;

  int ok = sscanf(buf, " %c,%lu,%u,%u,%f,%lu", &p, &th, &bh, &lh, &nf, &seed);
  if (ok < 6 || p != 'O') return false;
  if ((uint32_t)th != expectedTick) return false;

  *t = (uint32_t)th;
  *b = (uint16_t)bh;
  *l = (uint16_t)lh;
  *n = nf;
  return true;
}

static bool readSlave(uint8_t idx, uint32_t expectedTick) {
  uint8_t addr = SLAVE_ADDRESSES[idx];

  uint8_t n = Wire.requestFrom(addr, I2C_MAX_RX_BYTES);
  if (n == 0) return false;

  char buf[I2C_MAX_RX_BYTES + 1];
  uint8_t i = 0;
  while (Wire.available() && i < I2C_MAX_RX_BYTES) {
    buf[i++] = (char)Wire.read();
  }
  buf[i] = '\0';

  uint32_t t = 0;
  uint16_t b = 0, l = 0;
  uint8_t nB = 0;
  float nF = NAN;

  if (parseCompact(buf, expectedTick, &t, &b, &l, &nB)) {
    slaves[idx].tick = t;
    slaves[idx].bmask = b;
    slaves[idx].loss = l;
    slaves[idx].noise = (float)nB / 255.0f;
    slaves[idx].fmt = 2;
    slaves[idx].valid = true;
    slaves[idx].lastRxMs = millis();
    return true;
  }

  if (parseLong(buf, expectedTick, &t, &b, &l, &nF)) {
    slaves[idx].tick = t;
    slaves[idx].bmask = b;
    slaves[idx].loss = l;
    slaves[idx].noise = nF;
    slaves[idx].fmt = 1;
    slaves[idx].valid = true;
    slaves[idx].lastRxMs = millis();
    return true;
  }

  // Optional debug:
  // Serial.printf("[I2C] Parse fail addr=0x%02X exp=%lu got='%s'\n",
  //               (unsigned)addr, (unsigned long)expectedTick, buf);
  return false;
}

static void startNewTick() {
  tickCounter++;
  activeTick = tickCounter;

  tickInProgress = true;
  pollIndex = 0;
  lastPollStepMs = millis();

  for (uint8_t i = 0; i < NUM_SLAVES; i++) {
    slaves[i].wasValid = slaves[i].valid;
    slaves[i].valid = false;
    slaves[i].fmt = 0;
  }

  for (uint8_t i = 0; i < NUM_SLAVES; i++) {
    sendTickToSlave(SLAVE_ADDRESSES[i], activeTick);
  }

  Serial.printf("[I2C] Tick start=%lu\n", (unsigned long)activeTick);
}

// ============================================================================
// GAME ENGINE
// ============================================================================
static void saveSVG() {
  if (!sdOK) return;

  char filename[32];
  snprintf(filename, sizeof(filename), "/life_%lu.svg", (unsigned long)generation);

  File f = SD.open(filename, FILE_WRITE);
  if (!f) return;

  f.println("<?xml version=\"1.0\" encoding=\"UTF-8\" standalone=\"no\"?>");
  f.printf("<svg width=\"%d\" height=\"%d\" xmlns=\"http://www.w3.org/2000/svg\">\n", 128 * 4, 64 * 4);
  f.println("<rect width=\"100%\" height=\"100%\" fill=\"black\"/>");

  for (int x = 0; x < 128; x++) {
    for (int y = 0; y < 64; y++) {
      if (board[x] & (1ULL << y)) {
        f.printf("<rect x=\"%d\" y=\"%d\" width=\"3\" height=\"3\" fill=\"#00FF00\"/>\n", x * 4, y * 4);
      }
    }
  }

  f.println("</svg>");
  f.close();

  setLed(255, 255, 0);
  Serial.printf("[SD] Saved %s\n", filename);
}

static void randomizeBoard() {
  for (int x = 0; x < 128; x++) {
    uint64_t a = ((uint64_t)esp_random() << 32) | (uint64_t)esp_random();
    uint64_t b = ((uint64_t)esp_random() << 32) | (uint64_t)esp_random();
    board[x] = a ^ b;
    if (currentScale == 2) board[x] &= 0x00000000FFFFFFFFULL;
  }
}

static void resetGame() {
  randomizeBoard();
  generation = 0;
  population = 0;
  frozenState = false;
  loopDetected = false;

  for (uint8_t i = 0; i < HASH_BUF_SIZE; i++) hashHistory[i] = 0;
  hashIdx = 0;

  setLed(255, 255, 255);
  Serial.println("[GOL] Reset");
}

static void injectLife(int quadrant, uint16_t bmask) {
  int w = 128, h = 64;
  int startX = (quadrant % 2) * (w / 2) + (w / 8) + (esp_random() % 8);
  int startY = (quadrant / 2) * (h / 2) + (h / 8) + (esp_random() % 8);

  // Pattern selection (favoring gliders for equilibrium)
  uint8_t choice = (bmask >> 12) & 0x07;
  static const uint8_t G1[] = { 0x02, 0x01, 0x07 }; // Glider A
  static const uint8_t G2[] = { 0x04, 0x02, 0x07 }; // Glider B
  static const uint8_t B[] = { 0x03, 0x03 };        // Block

  if (choice < 3) { // 37.5% Glider A
    for (int i = 0; i < 3; i++) board[(startX + i) % w] |= ((uint64_t)G1[i] << (startY % 64));
  } else if (choice < 5) { // 25% Glider B
    for (int i = 0; i < 3; i++) board[(startX + i) % w] |= ((uint64_t)G2[i] << (startY % 64));
  } else if (choice == 5) { // 12.5% Block
    for (int i = 0; i < 2; i++) board[(startX + i) % w] |= ((uint64_t)B[i] << (startY % 64));
  } else { // 25% Sparse random (reduced)
    for (int i = 0; i < 4; i++) {
      if (bmask & (1 << (i*3))) {
        int xx = (startX + (i % 2) * 5) % w;
        int yy = (startY + (i / 2) * 5) % 64;
        board[xx] |= (1ULL << yy);
      }
    }
  }
}

static uint32_t getHash() {
  uint32_t h = 2166136261U;
  for (int i = 0; i < 128; i++) {
    const uint8_t* p = (const uint8_t*)&board[i];
    for (int j = 0; j < 8; j++) {
      h ^= p[j];
      h *= 16777619U;
    }
  }
  return h;
}

static void evolve() {
  if (frozenState) return;

  if (bmeOK) {
    ambientTemp = bme.readTemperature();
  }

  globalInjProb = 0.10f + (ambientTemp - 21.0f) * 0.005f;

  int conn = 0;
  for (int i = 0; i < NUM_SLAVES; i++) if (slaves[i].valid) conn++;

  if (conn == 0) globalInjProb = 0.0f;
  else if (globalInjProb < 0.01f) globalInjProb = 0.01f;

  if ((float)population / 8192.0f > 0.20f) globalInjProb = 0.0f;

  uint64_t next[128];
  uint32_t pop = 0;

  for (int x = 0; x < 128; x++) {
    uint64_t L = board[(x == 0) ? 127 : x - 1];
    uint64_t C = board[x];
    uint64_t R = board[(x == 127) ? 0 : x + 1];

    uint64_t Cu = (C >> 1) | (C << 63);
    uint64_t Cd = (C << 1) | (C >> 63);
    uint64_t Lu = (L >> 1) | (L << 63);
    uint64_t Ld = (L << 1) | (L >> 63);
    uint64_t Ru = (R >> 1) | (R << 63);
    uint64_t Rd = (R << 1) | (R >> 63);

    uint64_t s1 = Lu ^ L,  s2 = Lu & L;
    uint64_t s3 = Ld ^ Cu, s4 = Ld & Cu;
    uint64_t s5 = Cd ^ Ru, s6 = Cd & Ru;
    uint64_t s7 = R ^ Rd,  s8 = R & Rd;

    uint64_t a1 = s1 ^ s3;
    uint64_t a2 = (s1 & s3) ^ s2 ^ s4;
    uint64_t a3 = s2 & s4;

    uint64_t b1 = s5 ^ s7;
    uint64_t b2 = (s5 & s7) ^ s6 ^ s8;
    uint64_t b3 = s6 & s8;

    uint64_t sum1 = a1 ^ b1;
    uint64_t sum2 = (a1 & b1) ^ a2 ^ b2;
    uint64_t sum4 = (a2 & b2) | ((a1 & b1) & (a2 ^ b2)) | a3 | b3;

    uint64_t next_col = (sum2 & (sum1 | C)) & ~sum4;

    // Injection influenced by slaves validity (quadrant mapping kept from your code)
    // Injection (Gravity) Influenced by slaves — SIGNIFICANTLY THROTTLED
    if (globalInjProb > 0.001f) {
      int qX = (x < 64) ? 0 : 1;
      // 20x less noise than V2.3, only single-pixel mutations
      if (slaves[qX].valid && (esp_random() % 1000 < (int)(globalInjProb * 10.0f))) {
        next_col |= (1ULL << (esp_random() % 32));
      }
      if (slaves[qX + 2].valid && (esp_random() % 1000 < (int)(globalInjProb * 10.0f))) {
        next_col |= (1ULL << (32 + (esp_random() % 32)));
      }
    }

    next[x] = next_col;
  }

  if (oledOK) u8g2.clearBuffer();

  for (int x = 0; x < 128; x++) {
    board[x] = next[x];
    for (int y = 0; y < 64; y++) {
      if (board[x] & (1ULL << y)) {
        if (oledOK) {
          if (currentScale == 1) u8g2.drawPixel(x, y);
          else if (x < 64 && y < 32) u8g2.drawBox(x * 2, y * 2, 2, 2);
        }
        pop++;
      }
    }
  }

  population = pop;
  generation++;

  uint32_t h = getHash();
  bool found = false;
  for (int i = 0; i < HASH_BUF_SIZE; i++) if (hashHistory[i] == h) found = true;

  hashHistory[hashIdx] = h;
  hashIdx = (hashIdx + 1) % HASH_BUF_SIZE;

  if (found && generation > 50 && !loopDetected) {
    loopDetected = true;
    loopStartTime = millis();
  }

  if (oledOK) {
    for (int i = 0; i < NUM_SLAVES; i++) {
      if (slaves[i].valid) {
        int ix = (i % 2) ? 124 : 4;
        int iy = (i / 2) ? 55 : 8;
        u8g2.drawDisc(ix, iy, 2);
        if (millis() % 1000 < 200) u8g2.drawCircle(ix, iy, 4);
      }
    }

    u8g2.setDrawColor(1);
    u8g2.setFont(u8g2_font_4x6_tr);
    u8g2.setCursor(0, 63);
    u8g2.printf("GEN:%lu POP:%lu T:%.1fC INJ:%d%%",
                (unsigned long)generation,
                (unsigned long)population,
                (double)ambientTemp,
                (int)(globalInjProb * 100.0f));

    if (loopDetected) {
      int r = 10 - (int)((millis() - loopStartTime) / 1000);
      u8g2.drawBox(30, 25, 70, 15);
      u8g2.setDrawColor(0);
      u8g2.setCursor(35, 35);
      u8g2.printf("LOOP DETECT: %ds", r);
      u8g2.setDrawColor(1);

      setLed((millis() % 500 < 250) ? 255 : 50, 0, 0);
      if (r <= 0) resetGame();
    }

    if (frozenState) {
      u8g2.drawBox(20, 25, 90, 15);
      u8g2.setDrawColor(0);
      u8g2.setCursor(25, 35);
      u8g2.print("FROZEN STATE");
      u8g2.setDrawColor(1);
    }

    u8g2.sendBuffer();
  }
}

// ============================================================================
// HEALTH REPORTING
// ============================================================================
static void printHealth() {
  Serial.printf("=== HEALTH === I2C:%s OLED:%s BME:%s SD:%s tickInProg:%u tick=%lu gen=%lu pop=%lu\n",
                i2cOK ? "OK" : "X",
                oledOK ? "OK" : "X",
                bmeOK ? "OK" : "X",
                sdOK ? "OK" : "X",
                (unsigned)tickInProgress,
                (unsigned long)tickCounter,
                (unsigned long)generation,
                (unsigned long)population);

  for (uint8_t i = 0; i < NUM_SLAVES; i++) {
    Serial.printf("Slave[%u] addr=0x%02X valid:%u fmt:%u loss:%u noise:%.3f lastRx:%lums expTick:%lu\n",
                  (unsigned)i,
                  (unsigned)SLAVE_ADDRESSES[i],
                  (unsigned)slaves[i].valid,
                  (unsigned)slaves[i].fmt,
                  (unsigned)slaves[i].loss,
                  (double)(isnan(slaves[i].noise) ? 0.0f : slaves[i].noise),
                  (unsigned long)(millis() - slaves[i].lastRxMs),
                  (unsigned long)activeTick);
  }
}

// ============================================================================
// BUTTONS (NON-BLOCKING)
// BTNA short: reset game
// BTNA long : save SVG
// BTNB press: toggle scale
// ============================================================================
static bool btnAWasDown = false;
static uint32_t btnADownMs = 0;
static bool btnALongFired = false;

static bool lastB = true;

static void buttonsStep(uint32_t nowMs) {
  bool btnA = (digitalRead(BTNA_PIN) == LOW);
  bool btnB = (digitalRead(BTNB_PIN) == LOW);

  // --- Button A ---
  if (btnA && !btnAWasDown) {
    btnAWasDown = true;
    btnADownMs = nowMs;
    btnALongFired = false;
  }

  if (btnA && btnAWasDown && !btnALongFired && (nowMs - btnADownMs >= BTN_LONG_MS)) {
    btnALongFired = true;
    saveSVG();
  }

  if (!btnA && btnAWasDown) {
    uint32_t held = nowMs - btnADownMs;
    if (!btnALongFired && held < BTN_SHORT_MS) {
      resetGame();
    }
    btnAWasDown = false;
  }

  // --- Button B (edge detect) ---
  if (btnB && lastB) {
    currentScale = (currentScale == 1) ? 2 : 1;
    setLed(0, 255, 255);
    Serial.printf("[BTN] Scale=%d\n", currentScale);
  }
  lastB = !btnB ? true : false;
}

// ============================================================================
// SETUP & LOOP
// ============================================================================
void setup() {
  Serial.begin(115200);
  Serial.println();
  Serial.println("[SYSTEM] Cuantum Life V2.3 Boot");

  pinMode(BTNA_PIN, INPUT_PULLUP);
  pinMode(BTNB_PIN, INPUT_PULLUP);

  rgbLed.begin();
  rgbLed.setBrightness(50);
  rgbLed.show();
  setLed(255, 0, 255);

  // Init (never abort)
  initI2C();
  initOLED();
  initBME();
  initSD();

  resetGame();

  lastTickMs = millis();
  nextFrameMs = millis();
  nextRetryMs = millis() + RETRY_PERIOD_MS;
  lastHealthMs = millis();

  Serial.println("[SYSTEM] V2.3 Robust Core Online");
}

void loop() {
  uint32_t now = millis();

  // Buttons (non-blocking)
  buttonsStep(now);

  // Start new I2C tick periodically (if not already polling)
  if (!tickInProgress && (now - lastTickMs >= TICK_PERIOD_MS)) {
    lastTickMs = now;
    startNewTick();
  }

  // Poll slaves stepwise, with non-blocking breather
  if (tickInProgress) {
    if (now - lastPollStepMs >= I2C_BREATHER_MS) {
      lastPollStepMs = now;

      bool ok = readSlave(pollIndex, activeTick);
      if (ok) {
        if (!slaves[pollIndex].wasValid) {
          setLed(255, 255, 255);
          Serial.printf("[I2C] Slave linked addr=0x%02X fmt=%u\n",
                        (unsigned)SLAVE_ADDRESSES[pollIndex],
                        (unsigned)slaves[pollIndex].fmt);
        }
        // Stricter noise threshold and probabilistic pattern injection
        if (globalInjProb > 0.001f && !isnan(slaves[pollIndex].noise) && slaves[pollIndex].noise > 0.65f) {
          if (esp_random() % 100 < 40) injectLife(pollIndex, slaves[pollIndex].bmask);
        }
      }

      pollIndex++;
      if (pollIndex >= NUM_SLAVES) {
        tickInProgress = false;
        Serial.printf("[I2C] Tick done=%lu\n", (unsigned long)activeTick);
      }
    }
  }

  // Frame scheduler for Game of Life
  if ((int32_t)(now - nextFrameMs) >= 0) {
    evolve();

    float d = (float)population / 8192.0f;
    if (d < 0.05f) setLed(0, 0, 255);
    else if (d < 0.12f) setLed(0, 255, 0);
    else setLed(255, 0, 0);

    nextFrameMs = now + FRAME_TIME_MS;
  }

  // Periodic health report
  if (now - lastHealthMs >= HEALTH_PERIOD_MS) {
    lastHealthMs = now;
    printHealth();
  }

  // Periodic retries (non-spam)
  if (now >= nextRetryMs) {
    if (!bmeOK) initBME();
    if (!sdOK) initSD();
    nextRetryMs = now + RETRY_PERIOD_MS;
  }
}

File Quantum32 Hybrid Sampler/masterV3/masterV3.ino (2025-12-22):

/*
 * masterV3_hybrid_full.ino — Toy Holography Master (Non-Blocking, Full Peripherals)
 *
 * Keeps: OLED (U8g2 SH1106), RTC DS3231, SD logging (HSPI), BME280, NeoPixel, buttons
 * Adds: PC bidirectional Serial control + robust slave parsing (long + compact)
 *
 * Slave protocols supported:
 * 1) LONG (legacy):  "O,<tick>,<bmask>,<loss>,<noise>,<seed>\n"
 * 2) COMPACT (recommended): "O,%08lX,%04X,%04X,%02X\n"
 *     -> tickHex, bmaskHex, lossHex, noiseByte (0..255)
 *
 * Master -> Slave commands:
 * - Legacy tick: "T,<tick>,<mode>,<noise>\n"
 * - Optional params (if your slave supports it): "P,<noise>,<bias>,<kp>,<mode>\n"
 *
 * Serial commands (PC -> Master), line based:
 *   @HELLO
 *   @SET  N=0.20 M=1            (N=noise 0..1, M=mode)
 *   @PARAM N=0.20 B=5 K=60 M=1  (broadcast P command to slaves if supported)
 *   @GET  K=200 STRIDE=1 BURN=20
 *   @STOP
 *
 * Data output to PC during batch:
 *   O,<tick>,<slaveIndex>,<bmask>,<loss>,<noise>,<seedOr0>,<fmt>
 *     fmt: 0=invalid, 1=long, 2=compact
 *
 * Constraints:
 * - No while(1){}
 * - No return in setup() to abort
 * - Always continue init, use flags, retry in loop()
 */

#include <Wire.h>
#include <U8g2lib.h>
#include <RTClib.h>
#include <Adafruit_NeoPixel.h>
#include "FS.h"
#include "SD.h"
#include "SPI.h"
#include <Adafruit_Sensor.h>
#include <Adafruit_BME280.h>

// ============================================================================
// PIN DEFINITIONS (KEEP AS CURRENT WORKING HARDWARE)
// ============================================================================

// Buttons
static constexpr int BTNA_PIN = 1;
static constexpr int BTNB_PIN = 2;

// NeoPixel
static constexpr int RGB_LED_PIN = 48;
static constexpr uint8_t NUM_RGB_LEDS = 1;

// SD (HSPI)
static constexpr int SD_CS_PIN   = 7;
static constexpr int SD_MOSI_PIN = 6;
static constexpr int SD_MISO_PIN = 4;
static constexpr int SD_SCLK_PIN = 5;

// ============================================================================
// I2C ADDRESSES
// ============================================================================
static constexpr uint8_t OLED_ADDR = 0x3C;
static constexpr uint8_t RTC_ADDR  = 0x68;
static constexpr uint8_t BME_ADDR  = 0x76;

// Slaves
static constexpr uint8_t SLAVE_ADDRESSES[] = { 0x10, 0x11, 0x12, 0x13 };
static constexpr uint8_t NUM_SLAVES = sizeof(SLAVE_ADDRESSES) / sizeof(SLAVE_ADDRESSES[0]);

// ============================================================================
// I2C SETTINGS
// ============================================================================
static constexpr uint32_t I2C_CLOCK_SPEED = 100000;
static constexpr uint16_t I2C_TIMEOUT_MS  = 100;
static constexpr uint8_t  I2C_MAX_RX_BYTES = 32;

// ============================================================================
// TIMING (NON-BLOCKING SCHEDULER)
// ============================================================================
static constexpr uint32_t TICK_PERIOD_MS       = 1500;  // free-running tick if no PC batch
static constexpr uint32_t DISPLAY_PERIOD_MS    = 200;
static constexpr uint32_t HEALTH_PERIOD_MS     = 2000;
static constexpr uint32_t SD_RETRY_PERIOD_MS   = 10000;
static constexpr uint32_t BME_RETRY_PERIOD_MS  = 10000;
static constexpr uint32_t RTC_RETRY_PERIOD_MS  = 10000;
static constexpr uint32_t OLED_RETRY_PERIOD_MS = 10000;
static constexpr uint8_t  SLAVE_READS_PER_LOOP = 1;

// Buttons debounce (non-blocking)
static constexpr uint32_t BTN_DEBOUNCE_MS = 180;

// ============================================================================
// OLED (U8g2) — SH1106 1.3" 128x64
// ============================================================================
U8G2_SH1106_128X64_NONAME_F_HW_I2C display(U8G2_R0, U8X8_PIN_NONE);

// ============================================================================
// MODULES
// ============================================================================
RTC_DS3231 rtc;
Adafruit_NeoPixel rgbLed(NUM_RGB_LEDS, RGB_LED_PIN, NEO_GRB + NEO_KHZ800);
SPIClass spiSD(HSPI);
Adafruit_BME280 bme;

// ============================================================================
// GLOBAL FLAGS (NO ABORT IN SETUP)
// ============================================================================
static bool i2cOK  = false;
static bool oledOK = false;
static bool rtcOK  = false;
static bool sdOK   = false;
static bool bmeOK  = false;

// ============================================================================
// SLAVE DATA MODEL
// ============================================================================
struct SlaveObs {
  uint32_t tick = 0;
  uint16_t bmask = 0;
  uint16_t loss = 0;
  float noise = NAN;     // for long format
  uint8_t noiseByte = 0; // for compact format
  uint32_t seed = 0;
  uint8_t fmt = 0;       // 0 invalid, 1 long, 2 compact
  bool valid = false;
  uint32_t lastRxMs = 0;
};

static SlaveObs slaveObs[NUM_SLAVES];

// ============================================================================
// TOY BULK RECONSTRUCTION
// ============================================================================
static constexpr uint8_t N_LOGICALS = 6;
static constexpr uint8_t LOGICAL_REQ[N_LOGICALS] = {
  0b0001,
  0b0011,
  0b0110,
  0b1100,
  0b0101,
  0b1110
};

static uint8_t boundary_mask = 0;
static uint8_t bulk_mask = 0;
static float recon_ratio = 0.0f;

// ============================================================================
// ENV DATA
// ============================================================================
static float currentTemp = NAN;
static float currentHum  = NAN;

// ============================================================================
// STATE MACHINE
// ============================================================================
static uint32_t tickCounter = 0;
static uint32_t lastTickMs = 0;
static uint32_t lastDisplayMs = 0;
static uint32_t lastHealthMs = 0;
static uint32_t lastSdRetryMs = 0;
static uint32_t lastBmeRetryMs = 0;
static uint32_t lastRtcRetryMs = 0;
static uint32_t lastOledRetryMs = 0;

// History
static uint8_t reconHistory[70];
static uint8_t historyIdx = 0;

// Polling
static uint8_t pollIndex = 0;
static uint8_t slavesPolledThisTick = 0;
static bool tickInProgress = false;

// Simulation parameters
static uint8_t simMode = 1;
static float globalNoise = 0.05f; // 0..1

// Hybrid params (optional broadcast P)
static int8_t  globalBias = 0;    // -127..127
static uint8_t globalKp   = 0;    // 0..255

// SD
static constexpr const char* SD_FILENAME = "/datalog.csv";

// Batch driver (PC requested)
static bool batchActive = false;
static uint16_t batchRemaining = 0;
static uint16_t batchStride = 1;
static uint16_t batchBurn = 0;
static uint16_t strideCounter = 0;
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

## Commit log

2025-12-01 feat: Document new master features including BME280, SD logging, RGB LED, and ESP32-S3.
2025-12-02 feat: Implement initial I2C Master Opinion Analysis System with OLED, RTC, RGB LED, SD logging, and BME280 integration. add users buttons 1 and 2 to gnd input_pullup
2025-12-16 feat: introduce non-blocking master and slave nodes for Toy Holography system.
    [partitions.csv]
2025-12-22 feat: Initialize project environment with core dependencies and add MaxCut client script.
    [protoCuantum.brd, protoCuantum.sch, protoCuantumv2 (1).brd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]
2025-12-23 se agrega una version de pc_client_maxcutV2 y una explcacion de la nueva version
    [maxcut_V2_20251223_114408.csv, maxcut_V2_20251223_142507.csv, maxcut_dpg_20251222_192537.csv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]
2025-12-23 feat: Implement Cuantum Life V2.3.1, featuring independent I2C tick, non-blocking I2C/buttons, robust retries, and health reporting.
2025-12-29 feat: Add initial web portal for Quantum32 Hybrid Sampler with serial communication, data processing, and visualization.

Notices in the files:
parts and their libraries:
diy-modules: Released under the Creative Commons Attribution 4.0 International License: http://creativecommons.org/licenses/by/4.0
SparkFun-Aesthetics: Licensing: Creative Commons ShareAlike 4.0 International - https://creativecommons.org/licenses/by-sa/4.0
